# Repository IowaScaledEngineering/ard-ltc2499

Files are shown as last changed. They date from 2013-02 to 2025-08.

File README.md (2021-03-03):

# Iowa Scaled Engineering ARD-LTC2499

## Summary

The [ARD-LTC2499](https://www.iascaled.com/store/ARD-LTC2499) is an Arduino-compatible shield that contains a Linear Technology LTC2499 24-bit ADC
coupled with an LT6654 precision voltage reference. It is capable of converting 16 single-ended channels,
8 differential channels, or any other combination. In addition to measuring voltage, the ADC can interface
directly to a variety of sensors including strain gauges, thermocouples, and current shunts. The onboard EEPROM
can be used to store calibration and configuration information directly on each ARD-LTC2499 board.
A 6-byte EUI-48-compatible globally unique ID number is also provided.  The ARD-LTC2499 can be used with other
Arduino shields to make a simple, yet very accurate, data acquisition system.

Note:  The normal ARD-LTC2499 is not compatible with Arduinos using 3.3V I/O on the I2C lines, such as the Due, Zero, etc.
This is because the LTC2499 requires a 5V supply to deal with the 4.096V reference voltage, making it incompatible with 3.3V I2C.
A 3.3V compatible version is [available as the ARD-LTC2499-3V3](https://www.iascaled.com/store/ARD-LTC2499-3V3), which
is identical except that it also includes on-board level shifters for the I2C lines.

### Features

* Precision 24-bit delta sigma ADC in an Arduino-friendly form factor
* 16 single-ended channels, 8 differential channels, or any combination
* 7.5 samples/sec (or 15 samples/second without automatic offset cancellation)
* Input common mode voltage range of -0.3V to 5.3V
* Input measurement range of 0-2.048V (single-ended) or -2.048V to 2.048V (differential)
* 4.096V LT6654 precision voltage reference on board
* Optional onboard 5V linear regulator provides clean power to the ADC and reference
* 128 bytes of onboard EEPROM for storing configuration or calibration values
* Read-only 6-byte EUI-48-compatible globally unique ID
* Arduino software library for easy use
* 5V compatible I2C interface (or 3.3-5V with the ARD-LTC2499-3V3)

## Operation of the ARD-LTC2499 Hardware

The latest schematics for both the ARD-LTC2499 and the ARD-LTC2499-3V3 can be found here:
* [ARD-LTC2499 v1.3](https://github.com/IowaScaledEngineering/ard-ltc2499/raw/master/pg/ard-ltc2499-v1.3-83eb2df/ard-ltc2499.pdf)
* [ARD-LTC2499-3V3 v1.3](https://github.com/IowaScaledEngineering/ard-ltc2499/raw/master/pg/ard-ltc2499-v1.3LS-ffd4822/ard-ltc2499.pdf)

The Golden Rule:  When in doubt, check [the LTC2499
datasheet](https://www.analog.com/media/en/technical-documentation/data-sheets/2499fe.pdf).  This guide is not
designed to be a comprehensive guide to the LTC2499.

The useful measuring range of the inputs is 0V to 2.048V in single-ended mode, and a +/-2.048V in differential mode.
Be careful of common mode limits, however. Inputs have an absolute maximum common mode limit of -0.3V to +0.3V above VCC (nominally 5V)
before damage to the part will occur, so while the differential inputs can have -2.048V between them, neither side of the input may
violate the limit of -0.3V to 5.3V without damaging the part.

To eliminate any possibility of introducing gain or offset errors from buffering, the pins of the LTC2499 are brought directly
to the terminal headers. Please be careful when handling and using the board. Errant electrostatic discharge or voltages applied
outside the absolute maximum limits specified in the datasheet can cause immediate damage.

The 4.096V Reference output on J3 comes directly from the LT6654 reference output with no buffering. The LT6654 is rated for a
maximum of +/- 10mA. Also note that any current drawn from this pin will degrade the accuracy of the reference by a
small amount (see the Electrical Characteristics table, "Load Regulation", in the LT6654 datasheet).

### Hardware Configuration

In order to adapt to a wide variety of use cases and ArduinoTM configurations, the ARD-LTC2499 board has a number of configuration jumpers.

* JP1 - I2C Pull-up Enable
* JP2 - I2C Pin Selection
* JP3 - Onboard 5V Linear Regulator Enable
* JP4, JP5 & JP6 - LTC2499 I2C Address
* JP7 & JP8 - EEPROM I2C Address

_JP1 - I2C Pull-up Enable_

The I2C bus depends upon a set of pull-up resistors to function correctly. Each I2C bus should have one and only one set of
pull-ups enabled. The ARD-LTC2499 includes a set of 1.6k pull-up resistors that can be enabled by jumpering pins 1-2 and pins 3-4 of JP1.
Note that Arduino boards do not typically provide I2C pull-ups, so at least one board connected to I2C must provide them.

_JP2 - I2C Pin Selection_

Not all Arduinos provide I2C on the same pins. With the Rev 3 hardware designs (almost all of them as of 2021), there are now a
dedicated set of pins above AREF and GND marked "SDA" and "SCL". If you see those on your board, then place jumpers between
pins 3-5 and 4-6 on JP2 to connect the I2C bus to them.

If you board does not have explicit SDA and SCL pins, then most likely they're shared with pins A4 and A5. Place jumpers
between pins 1-3 and 2-4 to select those instead.

_JP3 - Onboard 5V Linear Regulator Enable_

To free the LTC2499 from any noise on the Arduino's 5V supply caused by the AVR or other shields, the ARD-LTC2499 includes an
onboard 78L05 regulator coming from the Arduino's "VIN" pin. If you are powering the Arduino with >8VDC via the power jack,
you can use the ARD-LTC2499 onboard 5V regulator to provide nice quiet power by jumpering pins 3-4 of JP3.

If you are powering the Arduino off of the 5V provided by USB or via some other means that does not place >8VDC on the VIN pin,
then the regulator will not work and must not be used. JP3 must be placed between pins 1-2 in this case.

_JP4, JP5 & JP6 - LTC2499 I2C Address_

Each device on the I2C bus must have a unique device address. The LTC2499 has 27 possible addresses depending on how
JP4, JP5, and JP6 are set. Each may be set high (jumpering pins 1-2, the two closest to the LTC2499), low (jumpering pins 3-4,
the ones furthest from the 2499) or floating (no jumpered pins or pins 2-3 jumpered).  JP4 corresponds to CA0, JP5 to CA1, and JP6 to CA2 on the LTC2499.

| JP4 | JP5 | JP6 | 7-bit I2C Address | Ard2499 Define |
|---|---|---|---|---|
| Low | Low | Low | 0x14 | ARD2499_ADC_ADDR_000 |
| Low | Low | Open | 0x15 | ARD2499_ADC_ADDR_00Z |
| Low | Low | High | 0x16 | ARD2499_ADC_ADDR_001 |
| Low | Open | Low | 0x17 | ARD2499_ADC_ADDR_0Z0 |
| Low | Open | Open | 0x24 | ARD2499_ADC_ADDR_0ZZ |
| Low | Open | High | 0x25 | ARD2499_ADC_ADDR_0Z1 |
| Low | High | Low | 0x26 | ARD2499_ADC_ADDR_010 |
| Low | High | Open | 0x27 | ARD2499_ADC_ADDR_01Z |
| Low | High | High | 0x28 | ARD2499_ADC_ADDR_011 |
| Open | Low | Low | 0x35 | ARD2499_ADC_ADDR_Z00 |
| Open | Low | Open | 0x36 | ARD2499_ADC_ADDR_Z0Z |
| Open | Low | High | 0x37 | ARD2499_ADC_ADDR_Z01 |
| Open | Open | Low | 0x44 | ARD2499_ADC_ADDR_ZZ0 |
| Open | Open | Open | 0x45 | ARD2499_ADC_ADDR_ZZZ |
| Open | Open | High | 0x46 | ARD2499_ADC_ADDR_ZZ1 |
| Open | High | Low | 0x47 | ARD2499_ADC_ADDR_Z10 |
| Open | High | Open | 0x54 | ARD2499_ADC_ADDR_Z1Z |
| Open | High | High | 0x55 | ARD2499_ADC_ADDR_Z11 |
| High | Low | Low | 0x56 | ARD2499_ADC_ADDR_100 |
| High | Low | Open | 0x57 | ARD2499_ADC_ADDR_10Z |
| High | Low | High | 0x64 | ARD2499_ADC_ADDR_101 |
| High | Open | Low | 0x65 | ARD2499_ADC_ADDR_1Z0 |
| High | Open | Open | 0x66 | ARD2499_ADC_ADDR_1ZZ |
| High | Open | High | 0x67 | ARD2499_ADC_ADDR_1Z1 |
| High | High | Low | 0x74 | ARD2499_ADC_ADDR_110 |
| High | High | Open | 0x75 | ARD2499_ADC_ADDR_11Z |
| High | High | High | 0x76 | ARD2499_ADC_ADDR_111 |

_JP7 & JP8 - EEPROM I2C Address_

Each device on the I2C bus must have a unique device address. The 24AA025E48 EEPROM that provides both non-volatile storage
and the globally unique ID number has four possible addresses depending on how JP7 and JP8 are set. Each may be set high (no jumper)
or low (jumper in place). Please refer to the Figure 5-2 in the 24AA025E48 datasheet (we use the SOT-23 version, so A2 is always '0' -
otherwise JP8 is A1 and JP7 is A0) or the Ard2499 library header for corresponding address values.

| JP7 | JP8 | 7-bit I2C Address | Ard2499 Define |
|---|---|---|---|
| Jumper | Jumper | 0x50 | ARD2499_EEP_ADDR_00 |
| Jumper | Open | 0x51 | ARD2499_EEP_ADDR_0Z |
| Open | Jumper | 0x52 | ARD2499_EEP_ADDR_Z0 |
| Open | Open | 0x53 | ARD2499_EEP_ADDR_ZZ |

## Ard2499 Arduino Software Library

### Introduction

The Ard2499 library was designed to make the Iowa Scaled Engineering ARD-LTC2499 shield easy to use with the Arduino environment.
The board itself is provides a breakout for the Linear Technology LTC2499 24-bit 8/16 channel delta-sigma ADC, adding other useful
features like a precision 4.096V LT6654 reference, 128 bytes of onboard EEPROM for storing configuration or calibration values,
and a read-only 6-byte EUI48-compatible globally unique ID number.

Note:  The software library is now maintained in [its own repository](https://github.com/IowaScaledEngineering/arduino-ard2499) for compatibility
with Arduino's Library Manager.

### Setup

There are two ways to install the Ard2499 library in the Arduino environment.

The easiest way is through Arduino's Library Manager.  You should be able to search for Ard2499 and have the library available for installation shortly.
We're working on it.

Alternately, you can [download the zip file](https://github.com/IowaScaledEngineering/arduino-ard2499/archive/main.zip) from the
IowaScaledEngineering/arduino-ard2499 project on Github and follow the ["Importing a .zip Library" instructions](https://www.arduino.cc/en/guide/libraries#toc4).

### Example Sketch

Once the library is installed, you should see Ard2499 under File->Examples in your Arduino environment.  A sample Arduino sketch that demonstrates some
simple uses of the library is available as ard2499_example directory.

### Library Usage Details

The core of the Ard2499 library is the Ard2499 object.  One instance should be instantiated for each ARD-LTC2499 board that you are using.

When an instance is created, an optional TwoWire object can be passed to the constructor.  Otherwise, the Ard2499 library assumes that the board will be communicating using the Wire object.

#### Functional Interface

```byte Ard2499::begin(byte ltc2499Address, byte eepromAddress, uint16_t referenceMillivolts = 4096);```

The Ard2499::begin() function should be called within the setup() function of your sketch. It requires the 7-bit address of both the LTC2499 and EEPROM on the ARD-LTC2499 to initialize both parts.
The addresses can be passed in directly as a number, or by using the address macros.  By using different addresses, it's possible to stack ARD-LTC2499 boards and have a different object to control each one.

An optional reference voltage, in millivolts, can be passed if the ARD-LTC2499 has a non-standard reference on board. If not specified, it defaults to 4096mV, which is the voltage
for any non-special order board.

Returns:  Ard2499::begin() will return a byte corresponding to a bitmast of errors, with 0 corresponding to complete success.
* ARD2499_SUCCESS (0x00) upon both devices being initialized successfully
* ARD2499_LTC2499_ERR (0x01) if the LTC2499 is not initialized successfully
* ARD2499_EEPROM_ERR (0x02) if the EEPROM is not initialized successfully

```byte Ard2499::ltc2499ChangeChannel(byte channel)```

The Ard2499::ltc2499ChangeChannel() function will wait for up to 200 milliseconds for the LTC2499 to become available, change the LTC2499's input multiplexer to the channel
specified in channel and start a new conversion. The value in channel corresponds to the lower 5 bits in the first configuration word of the device. In addition to computing
values for channel yourself, you can use the channel macros.

Additionally, channel can be configured to LTC2499_CHAN_TEMPERATURE to return the LTC2499 internal temperature. While the temperature input isn't a "channel" on the multiplexer,
the library makes it appear this way.

Returns:
* ARD2499_SUCCESS (0x00) if the channel change completed
* ARD2499_LTC2499_ERR (0x02) if the channel change failed

```byte Ard2499::ltc2499ChangeConfiguration(byte config)```

The Ard2499::ltc2499ChangeConfiguration() function will wait for up to 200 milliseconds for the LTC2499 to become available, change the LTC2499's configuration to that
specified in config and start a new conversion. The value in config corresponds to bits 3-5 in the second configuration word of the device. In addition to computing values
for config yourself, you can use the configuration macros.

Returns:
* ARD2499_SUCCESS (0x00) if the configuration change completed
* ARD2499_LTC2499_ERR (0x02) if the configuration change failed

```long Ard2499:: ltc2499Read()```

The Ard2499::ltc2499Read() function will wait for up to 200 milliseconds for the LTC2499 to become available, read the last conversion value, start a new conversion,
and clean up the conversion result.

Returns:
* -16777216 to +16777215 - normal conversion result
* LTC2499_READ_ERROR (0x01000001) if the read timed out or otherwise failed
* LTC2499_OVERRANGE_POSITIVE (0x01000000) if (IN+ - IN-) > 2.048V
* LTC2499_OVERRANGE_NEGATIVE (0x11000000) if (IN+ - IN-) < 2.048V

```long Ard2499:: ltc2499ReadAndChangeChannel(byte nextChannel)```

The Ard2499::ltc2499ReadAndChangeChannel() function will first attempt to change the input multiplexer channel and then perform a read. This is useful for not wasting
the conversion (and delay) resulting from a normal Ard2499::ltc2499Read() if the next operation is just going to be changing the input channel. Note: the channel change
does not take effect until after the data is read - in other words, for the next conversion.

Channel change behaviour works exactly like Ard2499::ltc2499ChangeChannel(). In the event that the channel change fails, LTC2499_READ_ERROR will be returned. Otherwise,
read and return behaviour works exactly like Ard2499::ltc2499Read().

```unsigned long Ard2499:: ltc2499ReadRaw()```

The Ard2499::ltc2499ReadRaw() function will wait for up to 200 milliseconds for the LTC2499 to become available, read the last conversion value, start a new conversion,
and return the native 32 bit conversion result. The lowest 6 bits will be "sub-LSB" bits, and the highest bit will be what the datasheet designates "SIG". This is for
advanced users who want direct access to the conversion result.

Returns:
* LTC2499_RAW_READ_ERROR (0xFFFFFFFF) if the read timed out or otherwise failed
* Any other result is a direct read from the LTC2499

```unsigned long Ard2499:: ltc2499ReadRawAndChangeChannel(byte nextChannel)```

The Ard2499::ltc2499ReadRawAndChangeChannel() function will first attempt to change the input multiplexer channel and then perform a raw read. This is useful for
not wasting the conversion (and delay) resulting from a normal Ard2499::ltc2499ReadRaw() if the next operation is just going to be changing the input channel.
Note: the channel change does not take effect until after the data is read - in other words, for the next conversion. The raw read capability is for advanced
users who want direct access to the conversion result.

Channel change behaviour works exactly like Ard2499::ltc2499ChangeChannel(). In the event that the channel change fails, LTC2499_RAW_READ_ERROR will be returned.
Otherwise, read and return behaviour works exactly like Ard2499:: ltc2499ReadRaw().

```unsigned int Ard2499:: ltc2499ReadTemperatureDeciK()```

The Ard2499::ltc2499ReadTemperatureDeciK() function will check if the current channel is LTC2499_CHAN_TEMPERATURE and if not, wait up to 200 milliseconds for
converter availability, change it and start a new conversion. It will then wait for up to 200 milliseconds for the LTC2499 to complete the conversion and turn it
into a unsigned int corresponding to the LTC2499's current temperature in 1/10th degrees Kelvin.

Upon failure, it will return zero, as hopefully no project you're working on is operating at absolute zero. If it is and the part still seems to be working
otherwise, call us and we'll help you write the paper for your physics journal of choice.

```float ltc2499ReadTemperature(byte temperatureUnits)```

The Ard2499::ltc2499ReadTemperature() function will check if the current channel is LTC2499_CHAN_TEMPERATURE and if not, wait up to 200 milliseconds for converter
availability, change it and start a new conversion. It will then wait for up to 200 milliseconds for the LTC2499 to complete the conversion and turn it into single
precision floating point value corresponding to the LTC2499's current temperature in the units specified in temperatureUnits.

Upon failure, it will return zero.

The value of temperatureUnits should be ARD2499_TEMP_K (degrees Kelvin), ARD2499_TEMP_C (degrees Celsius), or ARD2499_TEMP_F (degrees Fahrenheit).

Note: Because this function uses floating point on an 8 bit processor without any sort of hardware floating point support, expect performance to be abysmal on
AVR-based Arduinos. But it's handy if you don't care about performance.

```const char* Ard2499::eui48Get()```

The Ard2499::eui48Get() function will retrieve the board's 48-bit, globally unique, EUI-48TM-compatible identification number as a string.

Returns:

Ard2499::eui48Get() will return a character pointer to a constant, NULL-terminated string. The value will be either 12 characters of hexadecimal number,
or "Unknown" if the Ard2499::begin() failed to find the EEPROM. (Ard2499::begin() would have returned a value with the ARD2499_EEPROM_ERR bit set.)

```byte Ard2499::eepromRead(int address, byte defaultOnError=0x00)```

The Ard2499::eepromRead() function will retrieve a byte from the ARD-LTC2499's onboard EEPROM at the location specified by address. Valid values for address are 0x00-0x7F.

Optionally, the function can take a second argument - defaultOnError - of the value to be returned if the EEPROM is not initialized or is not accessible when the function
is called. If the defaultOnError parameter is omitted, it will default to returning 0x00 on failure.

```byte Ard2499::eepromWrite(int address, byte value, byte blocking=1)```

The Ard2499::eepromWrite() function will write a byte of value value to the ARD-LTC2499's onboard EEPROM at the location specified by address. Valid values for address are
0x00-0x7F, and value can be 0x00-0xFF.

Optionally, the function can take a third argument - blocking. The Microchip 24AA025E48 EEPROM used on the ARD-LTC2499 can take up to 5 milliseconds to actually commit
a write to EEPROM. If blocking is non-zero or omitted, the eepromWrite() function will block until it can confirm that the write is completed or until it times out
after 10 millseconds.

Note that blocking will not cause the value to be verified - it merely causes the function to block until the part begins acknowledging I2C/TWI transactions once
again, indicating that the write cycle is complete.

Returns:
* ARD2499_SUCCESS (0x00) if the write completed
* ARD2499_EEPROM_ERR (0x02) if the write failed

#### LTC2499 Address Defines

The address for the LTC2499 is configurable on the ARD-LTC2499 using jumpers JP4-JP6. You can either use the datasheet and directly enter the LTC2499's address into
the Ard2499::begin() function, or use some convenient macros.

The macros are all in the form of ARD2499_ADC_ADDR_cba, where a, b, and c can take on the value of '0', '1', or 'Z'. Placeholder 'a' represents jumper JP4, 'b' represents JP5,
and 'c' JP6. '0' indicates that the center pin is jumpered to the low pins (towards inputs 8-15 on the board), '1' indicates that it is jumpered to the high pins
(towards the LTC2499 or inputs 0-7), and 'Z' indicates that it's left floating (no jumpers or jumper across pin 2-3).

So, if all three were left open, you'd use ARD2499_ADC_ADDR_ZZZ. Likewise, for JP4 to bottom, JP5 to top, and JP6 open you'd use ARD2499_ADC_ADDR_Z10.

#### EEPROM Address Defines

The address for the EEPROM is configurable on the ARD-LTC2499 using jumpers JP7-JP8. You can either use the datasheet and directly enter the 24AA025E48's address into the
Ard2499::begin() function, or use some convenient macros.

The macros are all in the form of ARD2499_EEP_ADDR_ba, where a and b can take on the value of '0' or 'Z'. Placeholder 'a' represents jumper JP7 and 'b' represents JP8.
'0' indicates that a jumper has been placed across those pins, and 'Z' indicates that it's left floating (no jumper).

So, if both were left open, you'd use ARD2499_EEP_ADDR_ZZ. Likewise, for JP7 jumpered and JP8 open ARD2499_EEP_ADDR_Z0.

#### Channel Defines

The library provides definitions of all the common channel combinations to allow the easy selection of input channels without knowing all the internal LTC2499 bits to set.

Differential configurations take the form LTC2499_CHAN_DIFF_aP_bN, where 'a' represents the channel number of the positive input (IN+ in the LTC2499 datasheet)
and 'b' represents the channel number of the negative input (IN-).

Single-ended configurations are in the form LTC2499_CHAN_SINGLE_aP, where again 'a' represents the channel number of the positive (IN+) input.

Additionally, the internal temperature sensor can be selected by using LTC2499_CHAN_TEMPERATURE.

Some examples:
* LTC2499_CHAN_DIFF_2P_3N - Differential, input 2 is IN+, input 3 is IN-
* LTC2499_CHAN_DIFF_11P_10N - Differential, input 11 is IN+, input 10 is IN-
* LTC2499_CHAN_SINGLE_2P - Single ended, input 2 as IN+
* LTC2499_CHAN_SINGLE_10P - Single ended, input 10 as IN+
* LTC2499_CHAN_TEMPERATURE - Connect to internal temperature sensor.

#### Configuration Macros

Bit position macros are provided corresponding to the bits used to define the LTC2499 configuration in the second configuration byte:
* LTC2499_CONFIG2_FA
* LTC2499_CONFIG2_FB
* LTC2499_CONFIG2_SPD

These can be combined into a configuration value by an expression such as:

(_BV(LTC2499_CONFIG2_FA) | _BV(LTC2499_CONFIG2_SPD))

Please see the LTC2499 datasheet, Table 4, to see how these are used directly.

Additionally, the library has some convenient combinations:
* LTC2499_CONFIG2_50HZ_REJ - Reject at 50Hz
* LTC2499_CONFIG2_60HZ_REJ - Reject at 60Hz
* LTC2499_CONFIG2_60_50HZ_REJ - Reject at both 50/60Hz
* LTC2499_CONFIG2_SPEED_2X - Set for double speed conversions, drop offset calibration (15 samples/sec)

To use these, pick one of the rejection configurations and - optionally - bitwise or it with the double speed option and pass it to the the ltc2499ChangeConfiguration() function. For example:

```retval = ard2499.ltc2499ChangeConfiguration(LTC2499_CONFIG2_60_50HZ_REJ | LTC2499_CONFIG2_SPEED_2X)```

### A Note About Converter Latency

Important! Note that the LTC2499 will start a conversion whenever it is read (using ltc2499Read() or similar) or whenever the channel
or configuration is changed. Each conversion will take ~133 milliseconds in 1X mode and ~67 milliseconds in 2X mode. During this conversion time,
the LTC2499 will not respond to I2C/TWI requests. Thus, all calls interacting with the LTC2499 implement code to block until a sane timeout is
reached or the part starts responding. Be aware that when you use these functions, your code may hang up for a conversion time.

To minimize the wasted conversions, functions that read the current value and immediately change the channel (without wasting an entire
conversion cycle in between) are provided in addition to the standard read and channel change functions.

### Source Releases

The latest source code is always available from our GitHub [arduino-ard2499 repository](https://github.com/IowaScaledEngineering/arduino-ard2499).  We've broken it out
from the [main hardware project](https://github.com/IowaScaledEngineering/ard-ltc2499) to allow it to be included into Arduino's Library Manager automatically.

## Open Hardware & Software

Like all public Iowa Scaled Engineering designs, the ARD-LTC2499 is both open hardware and open source software.  The hardware is licensed under Creative Commons BY-SA, and the software is GPL v3.

The board was designed using the gEDA suite of tools (gschem, pcb, etc.), and the files are in the sch, sym, and pcb subdirectories.

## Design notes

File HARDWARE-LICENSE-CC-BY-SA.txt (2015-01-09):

The hardware design files for the Iowa Scaled Engineering ARD-LTC2499 are
open hardware, and licensed under the Creative Commons Attribution-Share
Alike license.

A copy can be found below, or from 
  http://creativecommons.org/licenses/by-sa/4.0/legalcode
-----------------------------------------------------------------------------

Creative Commons Attribution-ShareAlike 4.0 International Public License

By exercising the Licensed Rights (defined below), You accept and agree to
be bound by the terms and conditions of this Creative Commons
Attribution-ShareAlike 4.0 International Public License ("Public License").
To the extent this Public License may be interpreted as a contract, You are
granted the Licensed Rights in consideration of Your acceptance of these
terms and conditions, and the Licensor grants You such rights in
consideration of benefits the Licensor receives from making the Licensed
Material available under these terms and conditions.

Section 1 – Definitions.

    Adapted Material means material subject to Copyright and Similar Rights
that is derived from or based upon the Licensed Material and in which the
Licensed Material is translated, altered, arranged, transformed, or
otherwise modified in a manner requiring permission under the Copyright and
Similar Rights held by the Licensor. For purposes of this Public License,
where the Licensed Material is a musical work, performance, or sound
recording, Adapted Material is always produced where the Licensed Material
is synched in timed relation with a moving image.
    Adapter's License means the license You apply to Your Copyright and
Similar Rights in Your contributions to Adapted Material in accordance with
the terms and conditions of this Public License.
    BY-SA Compatible License means a license listed at
creativecommons.org/compatiblelicenses, approved by Creative Commons as
essentially the equivalent of this Public License.
    Copyright and Similar Rights means copyright and/or similar rights
closely related to copyright including, without limitation, performance,
broadcast, sound recording, and Sui Generis Database Rights, without regard
to how the rights are labeled or categorized. For purposes of this Public
License, the rights specified in Section 2(b)(1)-(2) are not Copyright and
Similar Rights.
    Effective Technological Measures means those measures that, in the
absence of proper authority, may not be circumvented under laws fulfilling
obligations under Article 11 of the WIPO Copyright Treaty adopted on
December 20, 1996, and/or similar international agreements.
    Exceptions and Limitations means fair use, fair dealing, and/or any
other exception or limitation to Copyright and Similar Rights that applies
to Your use of the Licensed Material.
    License Elements means the license attributes listed in the name of a
Creative Commons Public License. The License Elements of this Public License
are Attribution and ShareAlike.
    Licensed Material means the artistic or literary work, database, or
other material to which the Licensor applied this Public License.
    Licensed Rights means the rights granted to You subject to the terms and
conditions of this Public License, which are limited to all Copyright and
Similar Rights that apply to Your use of the Licensed Material and that the
Licensor has authority to license.
    Licensor means the individual(s) or entity(ies) granting rights under
this Public License.
    Share means to provide material to the public by any means or process
that requires permission under the Licensed Rights, such as reproduction,
public display, public performance, distribution, dissemination,
communication, or importation, and to make material available to the public
including in ways that members of the public may access the material from a
place and at a time individually chosen by them.
    Sui Generis Database Rights means rights other than copyright resulting
from Directive 96/9/EC of the European Parliament and of the Council of 11
March 1996 on the legal protection of databases, as amended and/or
succeeded, as well as other essentially equivalent rights anywhere in the
world.
    You means the individual or entity exercising the Licensed Rights under
this Public License. Your has a corresponding meaning.

Section 2 – Scope.

    License grant.
        Subject to the terms and conditions of this Public License, the
Licensor hereby grants You a worldwide, royalty-free, non-sublicensable,
non-exclusive, irrevocable license to exercise the Licensed Rights in the
Licensed Material to:
            reproduce and Share the Licensed Material, in whole or in part;
and
            produce, reproduce, and Share Adapted Material.
        Exceptions and Limitations. For the avoidance of doubt, where
Exceptions and Limitations apply to Your use, this Public License does not
apply, and You do not need to comply with its terms and conditions.
        Term. The term of this Public License is specified in Section 6(a).
        Media and formats; technical modifications allowed. The Licensor
authorizes You to exercise the Licensed Rights in all media and formats
whether now known or hereafter created, and to make technical modifications
necessary to do so. The Licensor waives and/or agrees not to assert any
right or authority to forbid You from making technical modifications
necessary to exercise the Licensed Rights, including technical modifications
necessary to circumvent Effective Technological Measures. For purposes of
this Public License, simply making modifications authorized by this Section
2(a)(4) never produces Adapted Material.
        Downstream recipients.
            Offer from the Licensor – Licensed Material. Every recipient of
the Licensed Material automatically receives an offer from the Licensor to
exercise the Licensed Rights under the terms and conditions of this Public
License.
            Additional offer from the Licensor – Adapted Material. Every
recipient of Adapted Material from You automatically receives an offer from
the Licensor to exercise the Licensed Rights in the Adapted Material under
the conditions of the Adapter’s License You apply.
            No downstream restrictions. You may not offer or impose any
additional or different terms or conditions on, or apply any Effective
Technological Measures to, the Licensed Material if doing so restricts
exercise of the Licensed Rights by any recipient of the Licensed Material.
        No endorsement. Nothing in this Public License constitutes or may be
construed as permission to assert or imply that You are, or that Your use of
the Licensed Material is, connected with, or sponsored, endorsed, or granted
official status by, the Licensor or others designated to receive attribution
as provided in Section 3(a)(1)(A)(i).

    Other rights.
        Moral rights, such as the right of integrity, are not licensed under
this Public License, nor are publicity, privacy, and/or other similar
personality rights; however, to the extent possible, the Licensor waives
and/or agrees not to assert any such rights held by the Licensor to the
limited extent necessary to allow You to exercise the Licensed Rights, but
not otherwise.
        Patent and trademark rights are not licensed under this Public
License.
        To the extent possible, the Licensor waives any right to collect
royalties from You for the exercise of the Licensed Rights, whether directly
or through a collecting society under any voluntary or waivable statutory or
compulsory licensing scheme. In all other cases the Licensor expressly
reserves any right to collect such royalties.

Section 3 – License Conditions.

Your exercise of the Licensed Rights is expressly made subject to the
following conditions.

    Attribution.

        If You Share the Licensed Material (including in modified form), You
must:
            retain the following if it is supplied by the Licensor with the
Licensed Material:
                identification of the creator(s) of the Licensed Material
and any others designated to receive attribution, in any reasonable manner
requested by the Licensor (including by pseudonym if designated);
                a copyright notice;
                a notice that refers to this Public License;
                a notice that refers to the disclaimer of warranties;
                a URI or hyperlink to the Licensed Material to the extent
                reasonably practicable;
            indicate if You modified the Licensed Material and retain an
indication of any previous modifications; and
            indicate the Licensed Material is licensed under this Public
License, and include the text of, or the URI or hyperlink to, this Public
License.
        You may satisfy the conditions in Section 3(a)(1) in any reasonable
manner based on the medium, means, and context in which You Share the
Licensed Material. For example, it may be reasonable to satisfy the
conditions by providing a URI or hyperlink to a resource that includes the
required information.
        If requested by the Licensor, You must remove any of the information
required by Section 3(a)(1)(A) to the extent reasonably practicable.
    ShareAlike.

    In addition to the conditions in Section 3(a), if You Share Adapted
Material You produce, the following conditions also apply.
        The Adapter’s License You apply must be a Creative Commons license
with the same License Elements, this version or later, or a BY-SA Compatible
License.
        You must include the text of, or the URI or hyperlink to, the
Adapter's License You apply. You may satisfy this condition in any
reasonable manner based on the medium, means, and context in which You Share
Adapted Material.
        You may not offer or impose any additional or different terms or
conditions on, or apply any Effective Technological Measures to, Adapted
Material that restrict exercise of the rights granted under the Adapter's
License You apply.

Section 4 – Sui Generis Database Rights.

Where the Licensed Rights include Sui Generis Database Rights that apply to
Your use of the Licensed Material:

    for the avoidance of doubt, Section 2(a)(1) grants You the right to
extract, reuse, reproduce, and Share all or a substantial portion of the
contents of the database;
    if You include all or a substantial portion of the database contents in
a database in which You have Sui Generis Database Rights, then the database
in which You have Sui Generis Database Rights (but not its individual
contents) is Adapted Material, including for purposes of Section 3(b); and
    You must comply with the conditions in Section 3(a) if You Share all or
a substantial portion of the contents of the database.

For the avoidance of doubt, this Section 4 supplements and does not replace
Your obligations under this Public License where the Licensed Rights include
other Copyright and Similar Rights.

Section 5 – Disclaimer of Warranties and Limitation of Liability.

    Unless otherwise separately undertaken by the Licensor, to the extent
possible, the Licensor offers the Licensed Material as-is and as-available,
and makes no representations or warranties of any kind concerning the
Licensed Material, whether express, implied, statutory, or other. This
includes, without limitation, warranties of title, merchantability, fitness
for a particular purpose, non-infringement, absence of latent or other
defects, accuracy, or the presence or absence of errors, whether or not
known or discoverable. Where disclaimers of warranties are not allowed in
full or in part, this disclaimer may not apply to You.
    To the extent possible, in no event will the Licensor be liable to You
on any legal theory (including, without limitation, negligence) or otherwise
for any direct, special, indirect, incidental, consequential, punitive,
exemplary, or other losses, costs, expenses, or damages arising out of this
Public License or use of the Licensed Material, even if the Licensor has
been advised of the possibility of such losses, costs, expenses, or damages.
Where a limitation of liability is not allowed in full or in part, this
limitation may not apply to You.

    The disclaimer of warranties and limitation of liability provided above
shall be interpreted in a manner that, to the extent possible, most closely
approximates an absolute disclaimer and waiver of all liability.

Section 6 – Term and Termination.

    This Public License applies for the term of the Copyright and Similar
Rights licensed here. However, if You fail to comply with this Public
License, then Your rights under this Public License terminate automatically.

    Where Your right to use the Licensed Material has terminated under
Section 6(a), it reinstates:
        automatically as of the date the violation is cured, provided it is
cured within 30 days of Your discovery of the violation; or
        upon express reinstatement by the Licensor.
    For the avoidance of doubt, this Section 6(b) does not affect any right
the Licensor may have to seek remedies for Your violations of this Public
License.
    For the avoidance of doubt, the Licensor may also offer the Licensed
Material under separate terms or conditions or stop distributing the
Licensed Material at any time; however, doing so will not terminate this
Public License.
    Sections 1, 5, 6, 7, and 8 survive termination of this Public License.

Section 7 – Other Terms and Conditions.

    The Licensor shall not be bound by any additional or different terms or
conditions communicated by You unless expressly agreed.
    Any arrangements, understandings, or agreements regarding the Licensed
Material not stated herein are separate from and independent of the terms
and conditions of this Public License.

Section 8 – Interpretation.

    For the avoidance of doubt, this Public License does not, and shall not
be interpreted to, reduce, limit, restrict, or impose conditions on any use
of the Licensed Material that could lawfully be made without permission
under this Public License.
    To the extent possible, if any provision of this Public License is
deemed unenforceable, it shall be automatically reformed to the minimum
extent necessary to make it enforceable. If the provision cannot be
reformed, it shall be severed from this Public License without affecting the
enforceability of the remaining terms and conditions.
    No term or condition of this Public License will be waived and no
failure to comply consented to unless expressly agreed to by the Licensor.
    Nothing in this Public License constitutes or may be interpreted as a
limitation upon, or waiver of, any privileges and immunities that apply to
the Licensor or You, including from the legal processes of any jurisdiction
or authority.

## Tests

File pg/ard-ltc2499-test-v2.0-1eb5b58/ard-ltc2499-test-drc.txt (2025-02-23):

** Drc report for /tank/data/design/projects/ard-ltc2499/kicad/ard-ltc2499-test/ard-ltc2499-test.kicad_pcb **
** Created on 2025-02-22 22:39:23 **

** Found 0 DRC violations **

** Found 0 unconnected pads **

** Found 0 Footprint errors **

** End of Report **

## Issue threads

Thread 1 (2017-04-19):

Add shorted solder jumper to connect COM to GND.

petersenm, 2017-04-19:
Allows option to float COM to some other voltage for lifted single-ended measurements.

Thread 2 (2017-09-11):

Inputs 8-15 collide with programming/SPI header on Arduino board

petersenm, 2017-09-11:

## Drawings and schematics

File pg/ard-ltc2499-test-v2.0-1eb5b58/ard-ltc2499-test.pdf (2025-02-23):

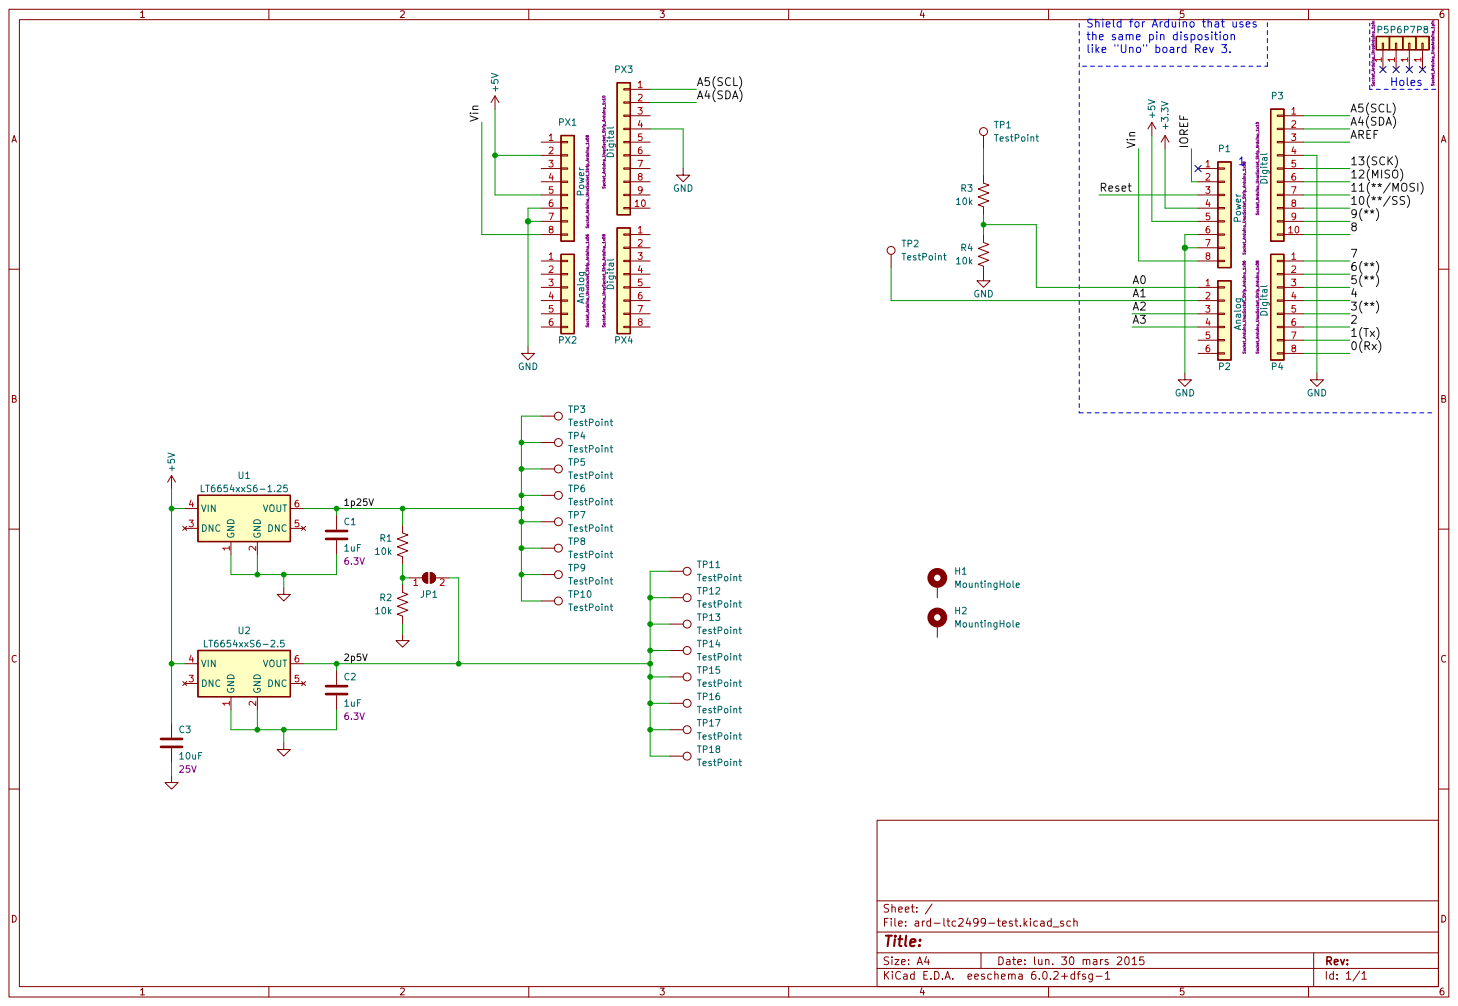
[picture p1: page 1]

the same pin disposition
like "Uno" board Rev 3.
1023456789 P3 Digital Socket_Arduino_Uno:Socket_Strip_Arduino_1x10 123456 P2 Analog Socket_Arduino_Uno:Socket_Strip_Arduino_1x06

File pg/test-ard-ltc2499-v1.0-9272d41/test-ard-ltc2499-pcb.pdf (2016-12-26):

# test-ard-ltc2499.pcb

# 1. Table of Contents (This Page) Created on Sun Dec 25 20:49:59 2016

# 2. component 3. solder 4. outline 5. plated-drill 6. unplated-drill 7. componentmask 8. soldermask 9. topsilk 10. bottomsilk 11. toppaste 12. topassembly 13. bottomassembly 14. fab

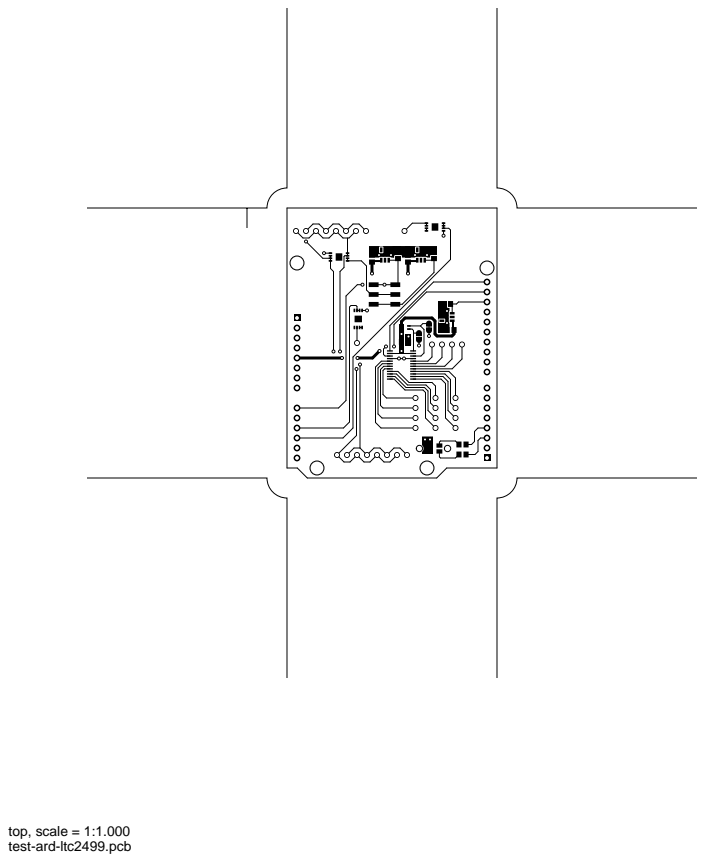
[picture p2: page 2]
top, scale = 1:1.000

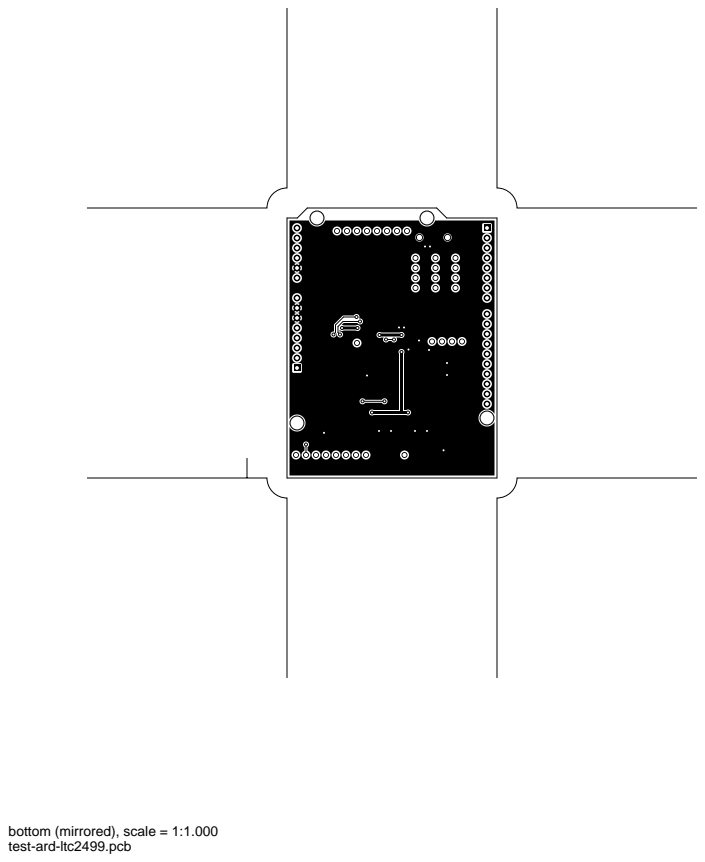
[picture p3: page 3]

bottom (mirrored), scale = 1:1.000

outline, scale = 1:1.000

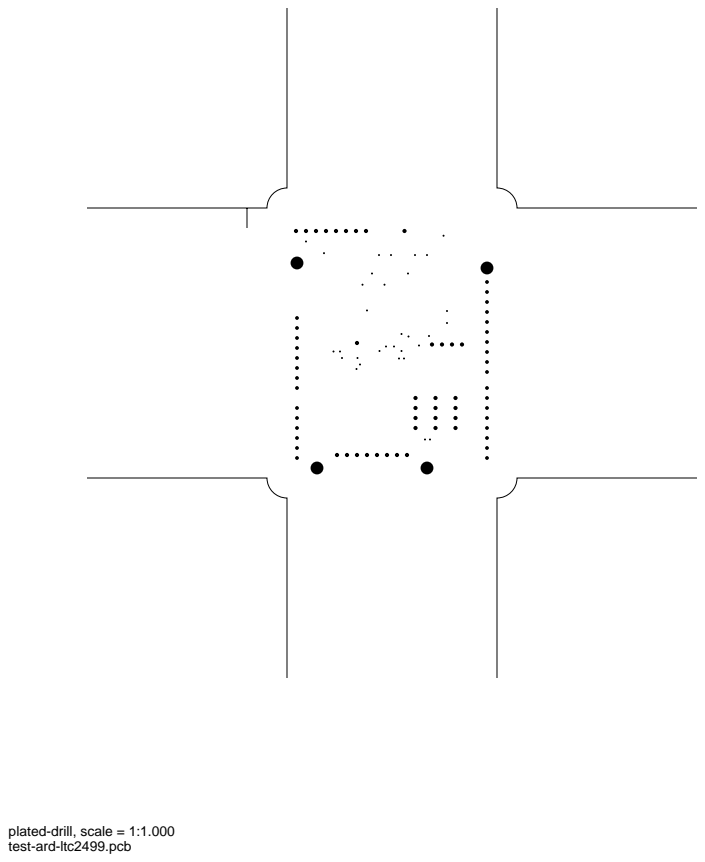
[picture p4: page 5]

plated-drill, scale = 1:1.000

unplated-drill, scale = 1:1.000

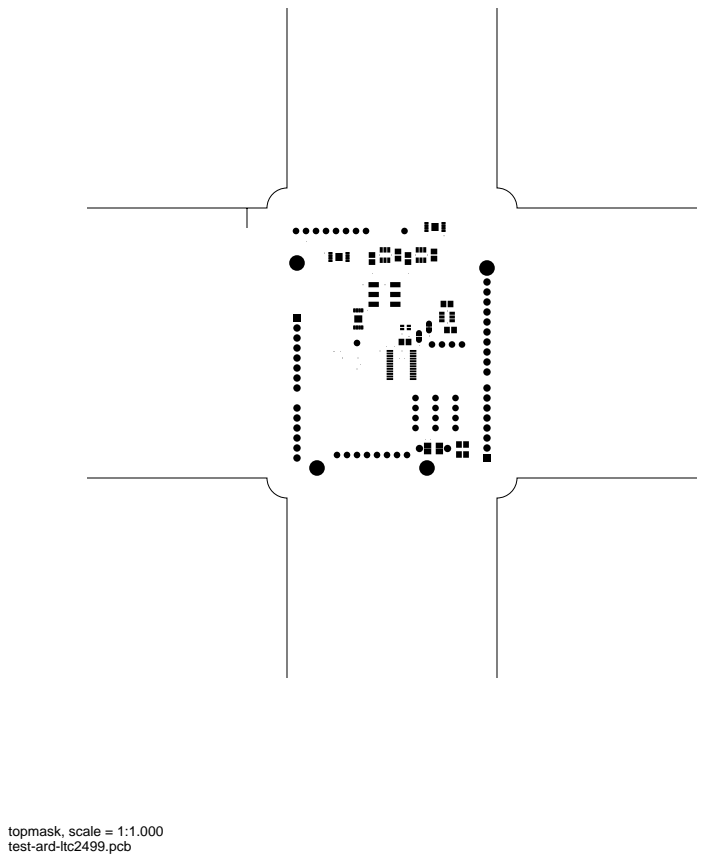
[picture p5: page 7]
topmask, scale = 1:1.000

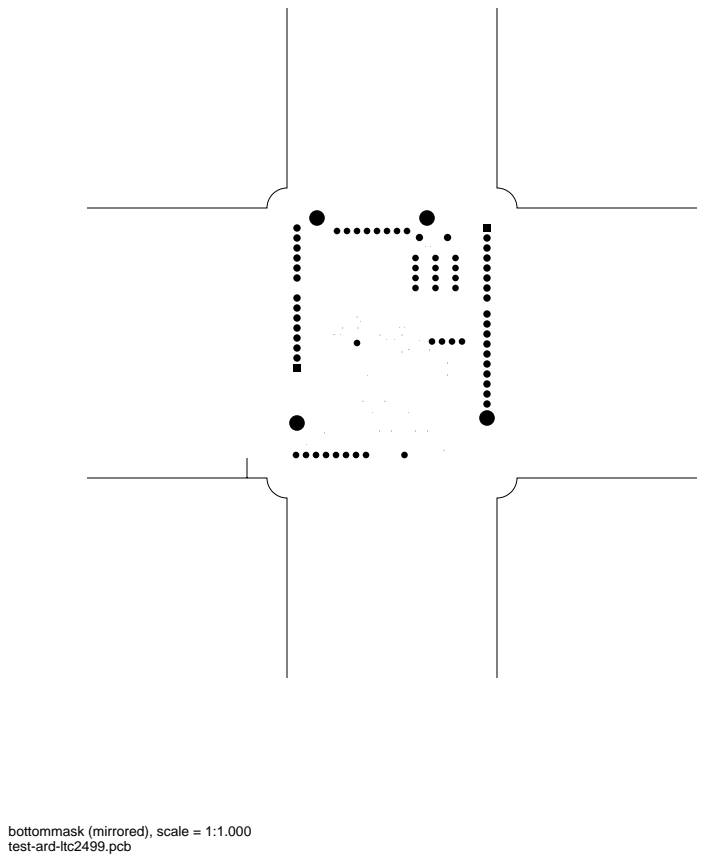
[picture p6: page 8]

bottommask (mirrored), scale = 1:1.000

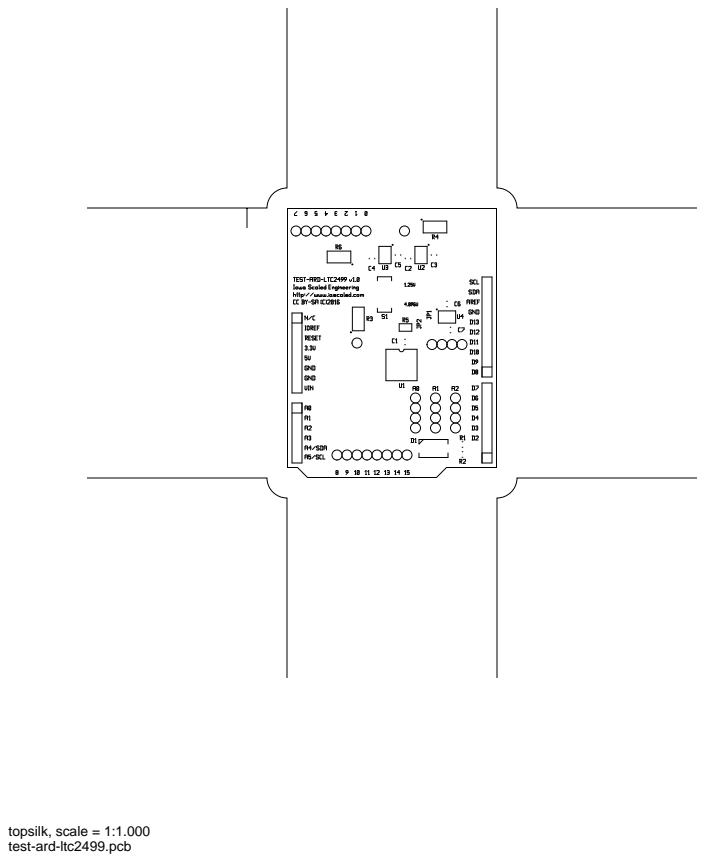
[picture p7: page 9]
topsilk, scale = 1:1.000

bottomsilk (mirrored), scale = 1:1.000

toppaste, scale = 1:1.000

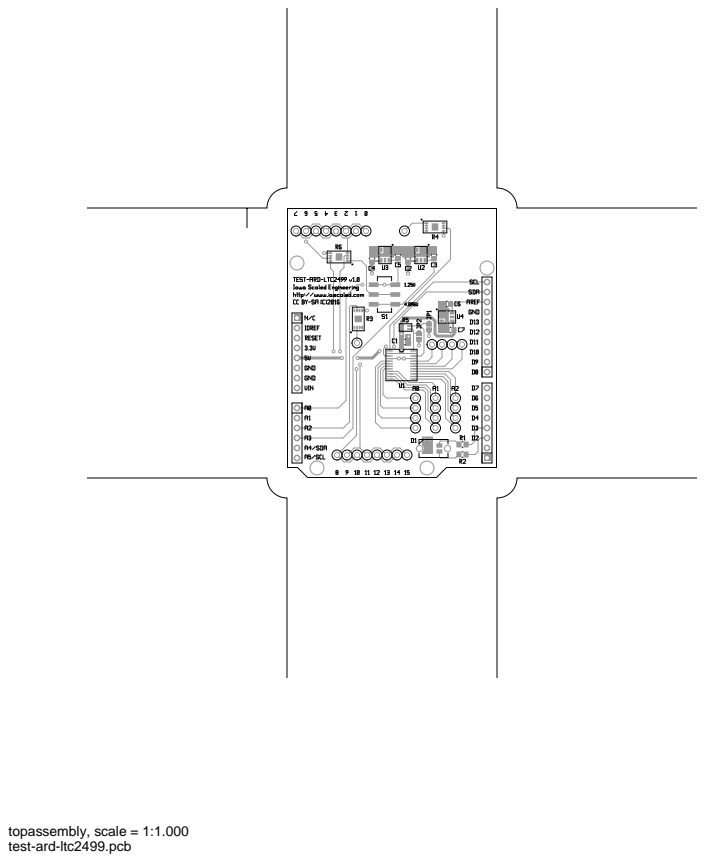
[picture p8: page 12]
topassembly, scale = 1:1.000

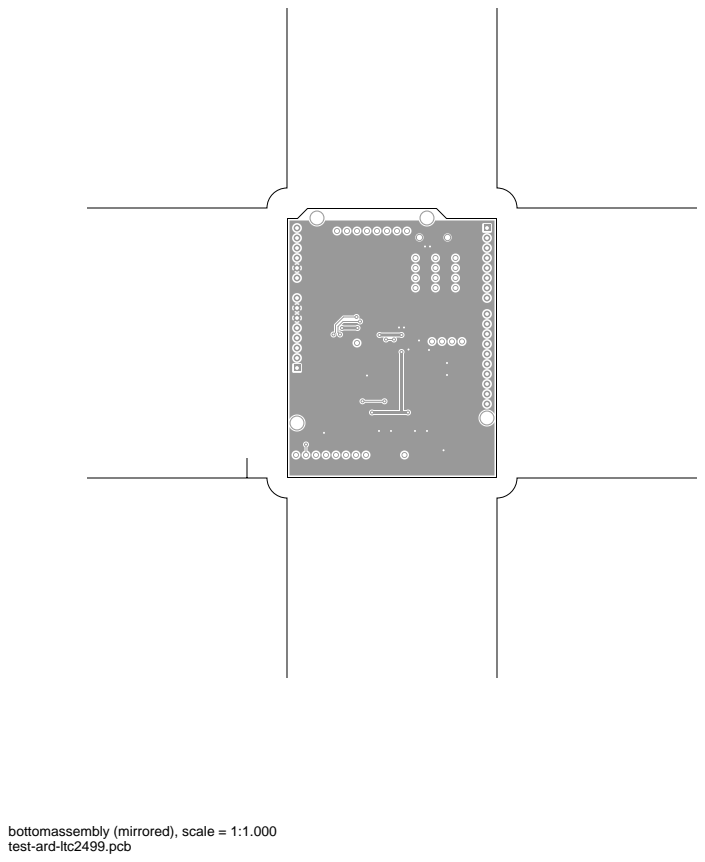
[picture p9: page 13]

bottomassembly (mirrored), scale = 1:1.000

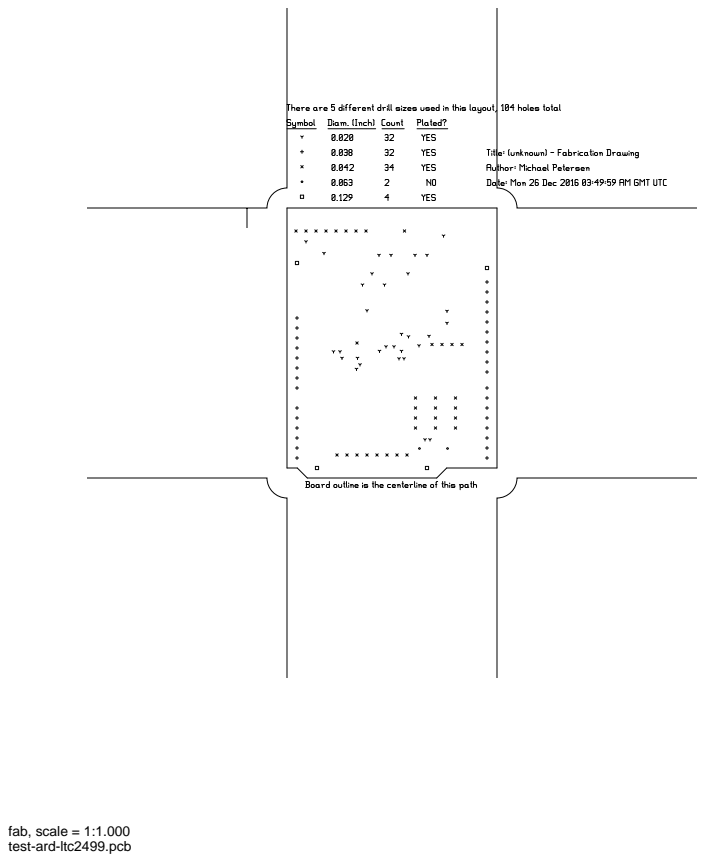
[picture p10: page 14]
fab, scale = 1:1.000

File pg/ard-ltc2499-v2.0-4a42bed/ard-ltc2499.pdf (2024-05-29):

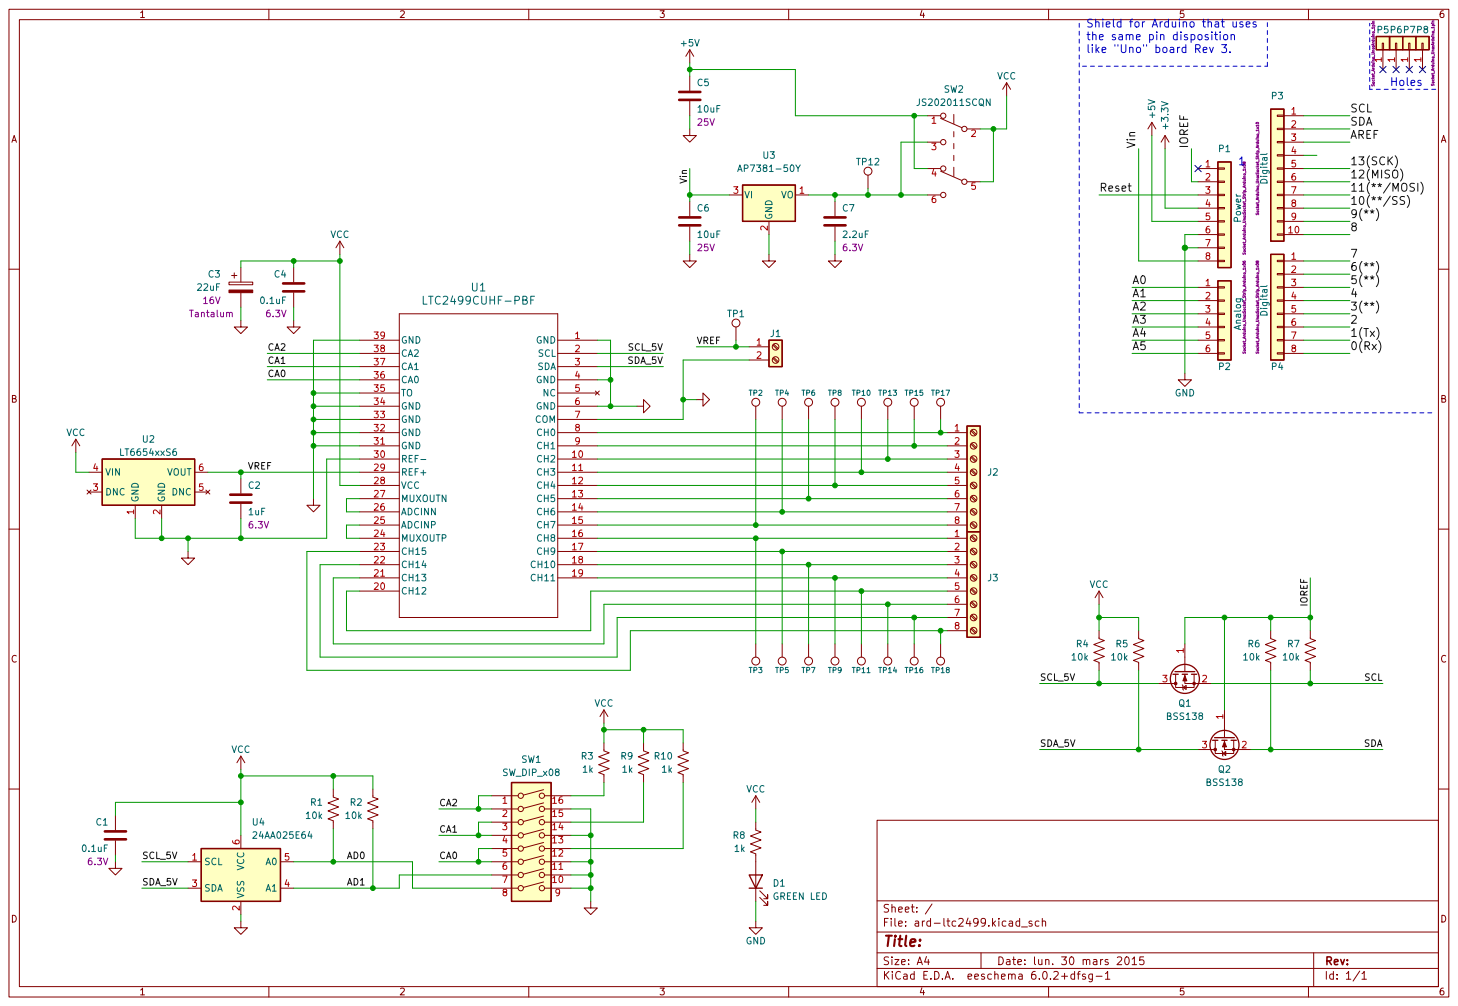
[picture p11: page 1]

Shield for Arduino that uses
the same pin disposition

2 DNC 3 VIN 4 DNC 5 VOUT 6 U2

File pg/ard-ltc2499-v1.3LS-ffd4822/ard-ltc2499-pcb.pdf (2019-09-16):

# ard-ltc2499.pcb

# 1. Table of Contents (This Page) Created on Thu Dec 22 11:12:02 2016

# 2. component 3. solder 4. outline 5. plated-drill 6. componentmask 7. soldermask 8. topsilk 9. bottomsilk 10. toppaste 11. bottompaste 12. topassembly 13. bottomassembly 14. fab

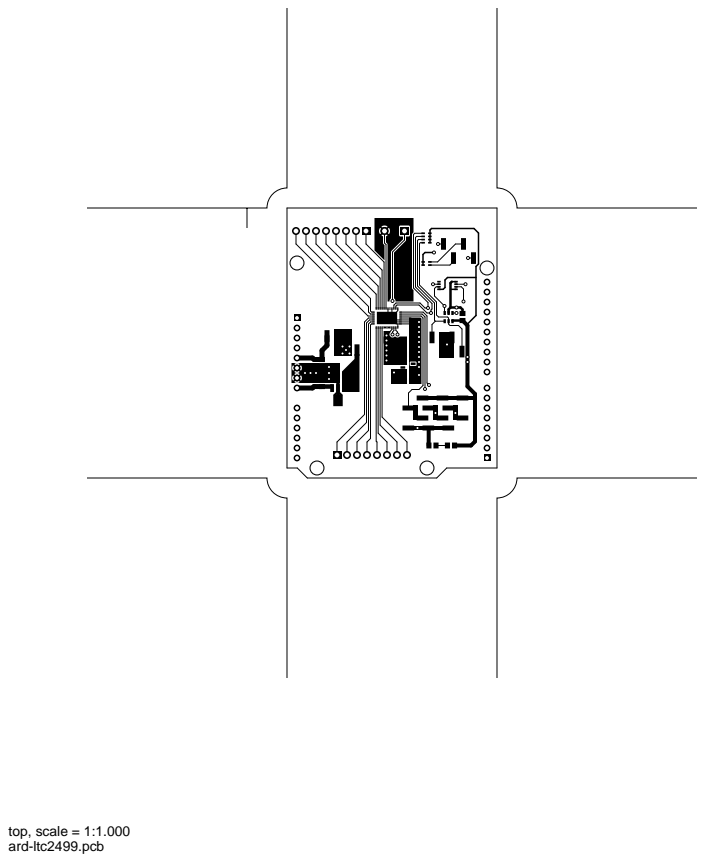
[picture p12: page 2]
top, scale = 1:1.000


bottom (mirrored), scale = 1:1.000

outline, scale = 1:1.000


plated-drill, scale = 1:1.000

topmask, scale = 1:1.000


bottommask (mirrored), scale = 1:1.000

topsilk, scale = 1:1.000


bottomsilk (mirrored), scale = 1:1.000

toppaste, scale = 1:1.000 bottompaste (mirrored), scale = 1:1.000

topassembly, scale = 1:1.000


bottomassembly (mirrored), scale = 1:1.000

fab, scale = 1:1.000

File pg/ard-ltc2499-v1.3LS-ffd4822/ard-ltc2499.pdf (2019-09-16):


SDA

5 READY

Place C2 and C3 near LTC2499 VCC pin.

Local regulator to provide quiet 5V.
Can only be used when VIN is present.

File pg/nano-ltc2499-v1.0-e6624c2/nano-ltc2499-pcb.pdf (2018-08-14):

# nano-ltc2499.pcb

# 1. Table of Contents (This Page) Created on Wed Aug 1 09:37:01 2018

# 2. component 3. solder 4. outline 5. plated-drill 6. componentmask 7. soldermask 8. topsilk 9. bottomsilk 10. toppaste 11. topassembly 12. bottomassembly 13. fab

top, scale = 1:1.000


bottom (mirrored), scale = 1:1.000

outline, scale = 1:1.000


plated-drill, scale = 1:1.000

topmask, scale = 1:1.000


bottommask (mirrored), scale = 1:1.000


topsilk, scale = 1:1.000


bottomsilk (mirrored), scale = 1:1.000

toppaste, scale = 1:1.000

topassembly, scale = 1:1.000


bottomassembly (mirrored), scale = 1:1.000

fab, scale = 1:1.000

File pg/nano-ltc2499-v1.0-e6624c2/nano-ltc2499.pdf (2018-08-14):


Place C5 and C6 near LTC2499 VCC pin.

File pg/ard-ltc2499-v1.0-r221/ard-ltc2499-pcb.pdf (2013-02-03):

# ard-ltc2499.pcb

# 1. Table of Contents (This Page) Created on Sat Feb 2 13:58:03 2013

# 2. component 3. solder 4. outline 5. plated-drill 6. componentmask 7. soldermask 8. topsilk 9. bottomsilk 10. toppaste 11. topassembly 12. bottomassembly 13. fab

top, scale = 1:1.000


bottom (mirrored), scale = 1:1.000

outline, scale = 1:1.000


plated-drill, scale = 1:1.000

topmask, scale = 1:1.000


bottommask (mirrored), scale = 1:1.000

topsilk, scale = 1:1.000

bottomsilk (mirrored), scale = 1:1.000

toppaste, scale = 1:1.000

topassembly, scale = 1:1.000


bottomassembly (mirrored), scale = 1:1.000

fab, scale = 1:1.000

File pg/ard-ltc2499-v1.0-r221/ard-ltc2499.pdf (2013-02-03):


J3 − Arduino I2C Pins
Older Arduinos use A4/A5
Newer Arduinos use SDA/SCL

3 | 4 | SCL

Place C2 and C3 near LTC2499 VCC pin.

Local regulator to provide quiet 5V.
Can only be used when VIN is present.


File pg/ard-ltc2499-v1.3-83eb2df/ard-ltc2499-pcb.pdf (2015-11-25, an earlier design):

# ard-ltc2499.pcb

# 1. Table of Contents (This Page) Created on Wed Nov 25 10:30:26 2015

# 2. component 3. solder 4. outline 5. plated-drill 6. componentmask 7. soldermask 8. topsilk 9. bottomsilk 10. toppaste 11. topassembly 12. bottomassembly 13. fab

top, scale = 1:1.000


bottom (mirrored), scale = 1:1.000

outline, scale = 1:1.000


plated-drill, scale = 1:1.000

topmask, scale = 1:1.000


bottommask (mirrored), scale = 1:1.000

topsilk, scale = 1:1.000

bottomsilk (mirrored), scale = 1:1.000

toppaste, scale = 1:1.000

topassembly, scale = 1:1.000


bottomassembly (mirrored), scale = 1:1.000

fab, scale = 1:1.000

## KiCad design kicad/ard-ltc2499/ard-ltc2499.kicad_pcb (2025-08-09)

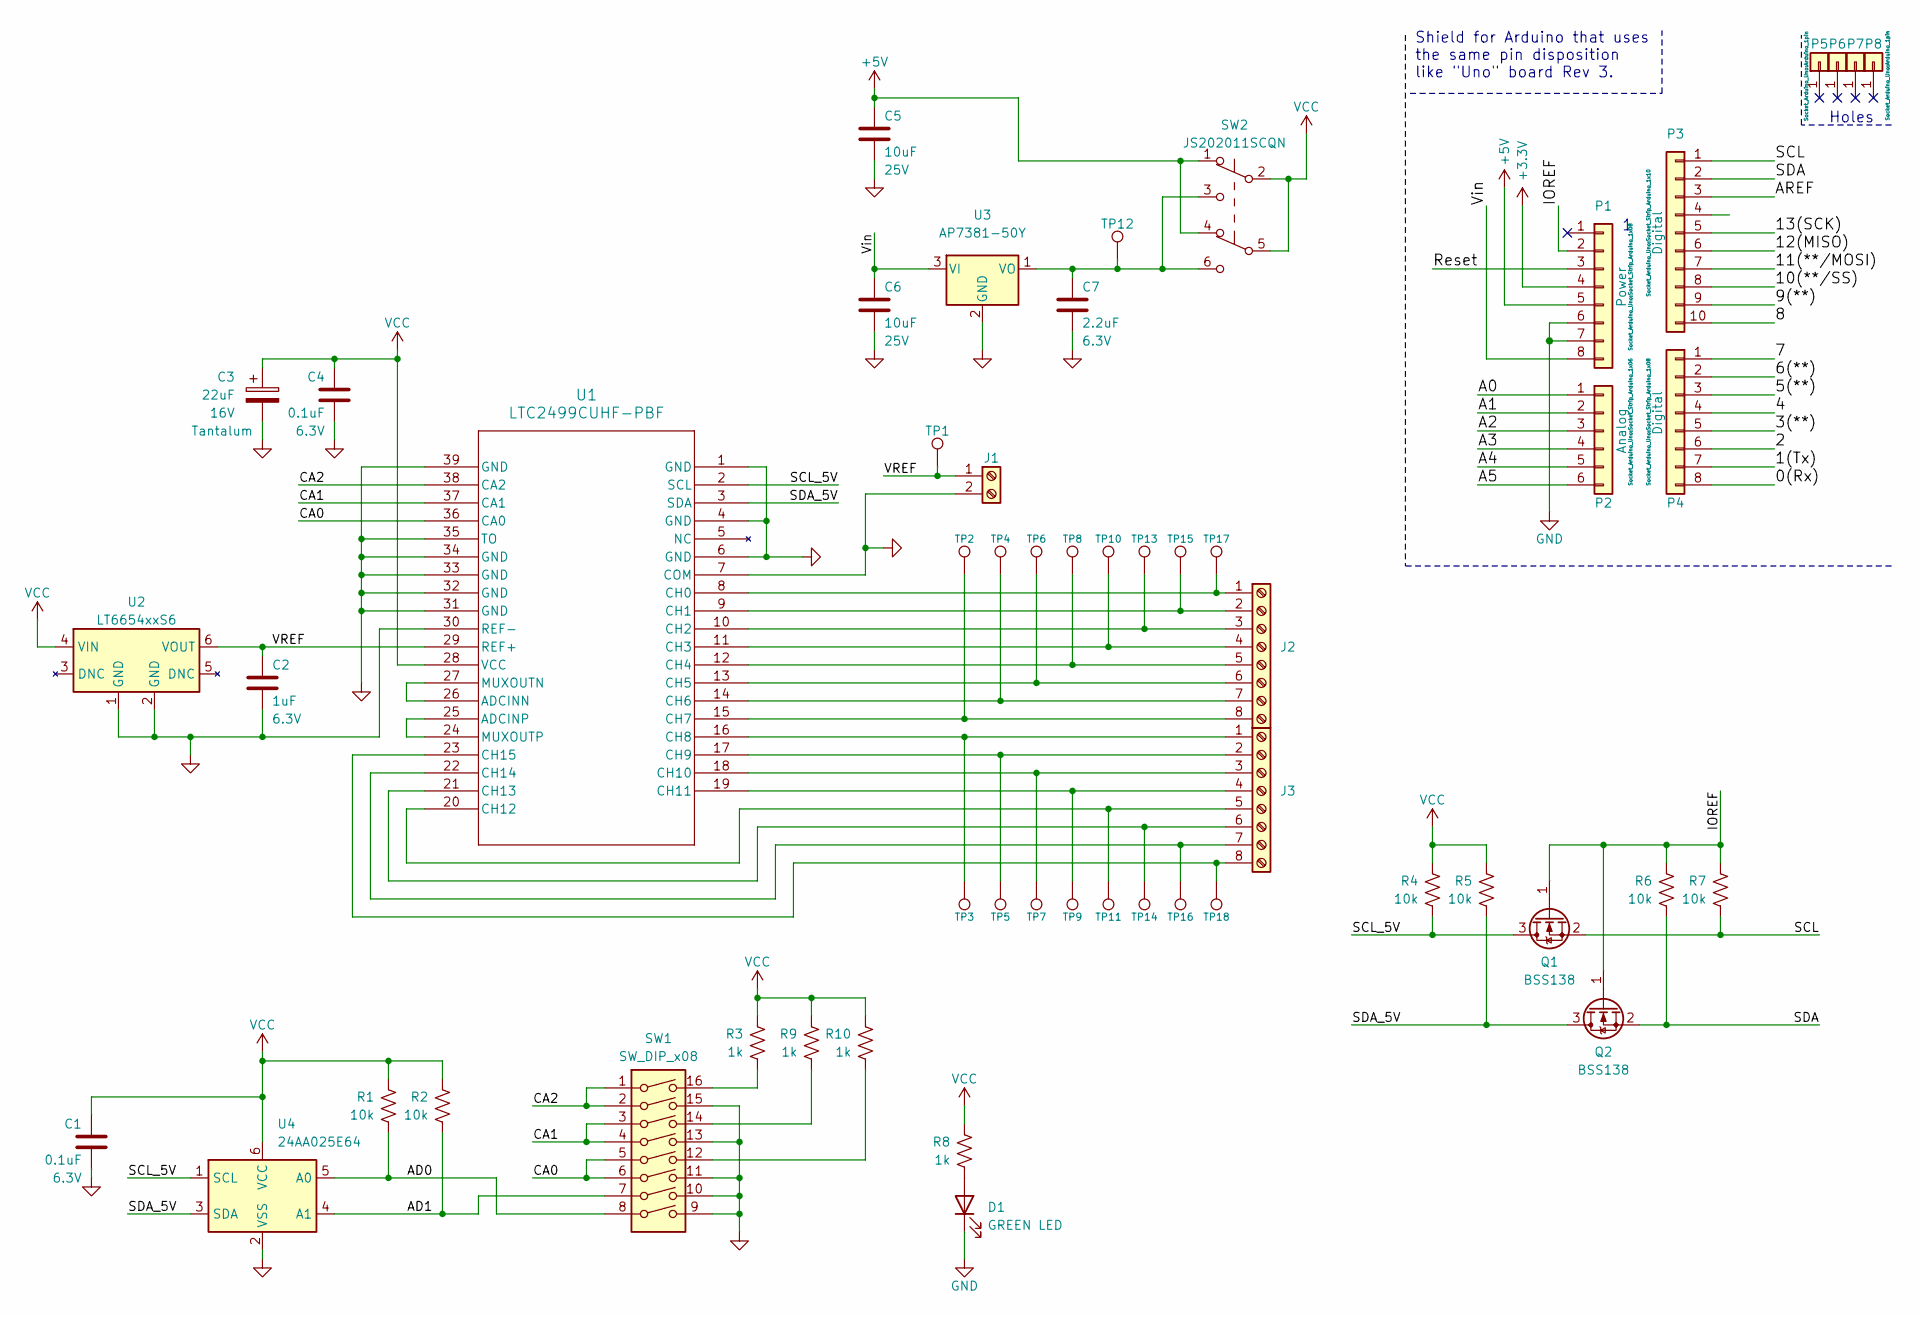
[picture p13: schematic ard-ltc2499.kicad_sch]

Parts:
C1, C4: 0.1uF; C_0805_2012Metric; Voltage 6.3V
C2: 1uF; C_0805_2012Metric; Voltage 6.3V
C3: 22uF; CP_EIA-3216-18_Kemet-A; Voltage 16V
C5, C6: 10uF; C_0805_2012Metric; Voltage 25V
C7: 2.2uF; C_0805_2012Metric; Voltage 6.3V
D1: GREEN LED; LED_0805_2012Metric
J1: Screw_Terminal_01x02; TerminalBlock_RND_205-00012_1x02_P5.00mm_Horizontal
J2, J3: Screw_Terminal_01x08; TerminalBlock_TE_282834-8_1x08_P2.54mm_Horizontal
P1: Power; Socket_Strip_Arduino_1x08
P2: Analog; Socket_Strip_Arduino_1x06
P3: Digital; Socket_Strip_Arduino_1x10
P4: Digital; Socket_Strip_Arduino_1x08
P5, P6, P7, P8: CONN_01X01; Arduino_1pin
Q1, Q2: BSS138; SOT-23
R1, R2, R4, R5, R6, R7: 10k; R_0805_2012Metric
R3, R8, R9, R10: 1k; R_0805_2012Metric
SW1: SW_DIP_x08; SW_DIP_SPSTx08_Slide_6.7x21.88mm_W8.61mm_P2.54mm_LowProfile
SW2: JS202011SCQN; SW_JS202011SCQN
TP1, TP2, TP3, TP4, TP5, TP6, TP7, TP8, TP9, TP10, TP11, TP12, TP13, TP14, TP15, TP16, TP17, TP18: TestPoint; TestPoint_Pad_D1.5mm
U1: LTC2499CUHF-PBF; QFN-38_UHF_LIT
U2: LT6654xxS6; TSOT-23-6
U3: AP7381-50Y; SOT-89-3
U4: 24AA025E64; TSOT-23-6

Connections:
+3V3: P1.4
+5V: C5.1, P1.5, SW2.1 (A), SW2.4 (A)
/0(Rx): P4.8
/1(Tx): P4.7
/2: P4.6
/3(**): P4.5
/4: P4.4
/5(**): P4.3
/6(**): P4.2
/7: P4.1
/8: P3.10
/9(**): P3.9
/10(**/SS): P3.8
/11(**/MOSI): P3.7
/12(MISO): P3.6
/13(SCK): P3.5
/A0: P2.1
/A1: P2.2
/A2: P2.3
/A3: P2.4
/A4: P2.5
/A5: P2.6
/AD0: R1.1, SW1.8, U4.5 (A0)
/AD1: R2.1, SW1.7, U4.4 (A1)
/AREF: P3.3
/CA0: SW1.5, SW1.6, U1.36 (CA0)
/CA1: SW1.3, SW1.4, U1.37 (CA1)
/CA2: SW1.1, SW1.2, U1.38 (CA2)
/IOREF: P1.2, Q1.1 (G), Q2.1 (G), R6.2, R7.2
/Reset: P1.3
/SCL: P3.1, Q1.2 (S), R7.1
/SCL_5V: Q1.3 (D), R4.1, U1.2 (SCL), U4.1 (SCL)
/SDA: P3.2, Q2.2 (S), R6.1
/SDA_5V: Q2.3 (D), R5.1, U1.3 (SDA), U4.3 (SDA)
/VREF: C2.1, J1.1, TP1.1, U1.29 (REF+), U2.6 (VOUT)
/Vin: C6.1, P1.8, U3.3 (VI)
GND: C1.2, C2.2, C3.2, C4.2, C5.2, C6.2, C7.2, D1.1 (K), J1.2, P1.6, P1.7, SW1.9, SW1.10, SW1.11, SW1.13, SW1.15, U1.1 (GND), U1.4 (GND), U1.6 (GND), U1.7 (COM), U1.30 (REF-), U1.31 (GND), U1.32 (GND), U1.33 (GND), U1.34 (GND), U1.35 (TO), U1.39 (GND), U2.1 (GND), U2.2 (GND), U3.2 (GND), U4.2 (VSS)
unnamed: C7.1, SW2.3 (C), SW2.6 (C), TP12.1, U3.1 (VO)
unnamed: D1.2 (A), R8.1
unnamed: J2.1, TP17.1, U1.8 (CH0)
unnamed: J2.2, TP15.1, U1.9 (CH1)
unnamed: J2.3, TP13.1, U1.10 (CH2)
unnamed: J2.4, TP10.1, U1.11 (CH3)
unnamed: J2.5, TP8.1, U1.12 (CH4)
unnamed: J2.6, TP6.1, U1.13 (CH5)
unnamed: J2.7, TP4.1, U1.14 (CH6)
unnamed: J2.8, TP2.1, U1.15 (CH7)
unnamed: J3.1, TP3.1, U1.16 (CH8)
unnamed: J3.2, TP5.1, U1.17 (CH9)
unnamed: J3.3, TP7.1, U1.18 (CH10)
unnamed: J3.4, TP9.1, U1.19 (CH11)
unnamed: J3.5, TP11.1, U1.20 (CH12)
unnamed: J3.6, TP14.1, U1.21 (CH13)
unnamed: J3.7, TP16.1, U1.22 (CH14)
unnamed: J3.8, TP18.1, U1.23 (CH15)
unnamed: R3.1, SW1.16
unnamed: R9.1, SW1.14
unnamed: R10.1, SW1.12
unnamed: U1.24 (MUXOUTP), U1.25 (ADCINP)
unnamed: U1.26 (ADCINN), U1.27 (MUXOUTN)
VCC: C1.1, C3.1, C4.1, R1.2, R2.2, R3.2, R4.2, R5.2, R8.2, R9.2, R10.2, SW2.2 (B), SW2.5 (B), U1.28 (VCC), U2.4 (VIN), U4.6 (VCC)

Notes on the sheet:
Holes
Shield for Arduino that uses the same pin disposition like "Uno" board Rev 3.

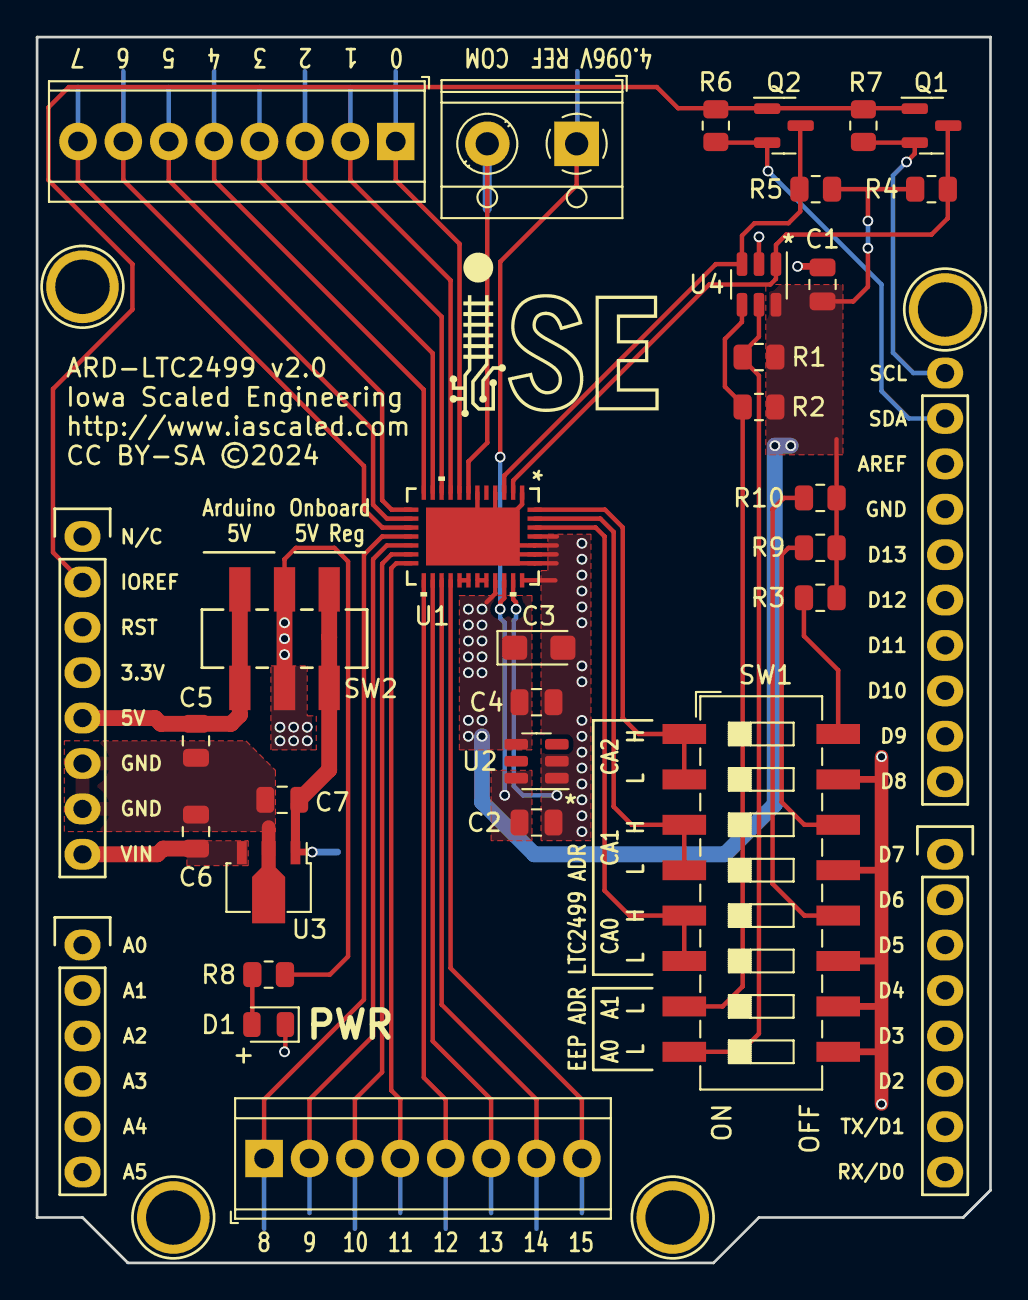
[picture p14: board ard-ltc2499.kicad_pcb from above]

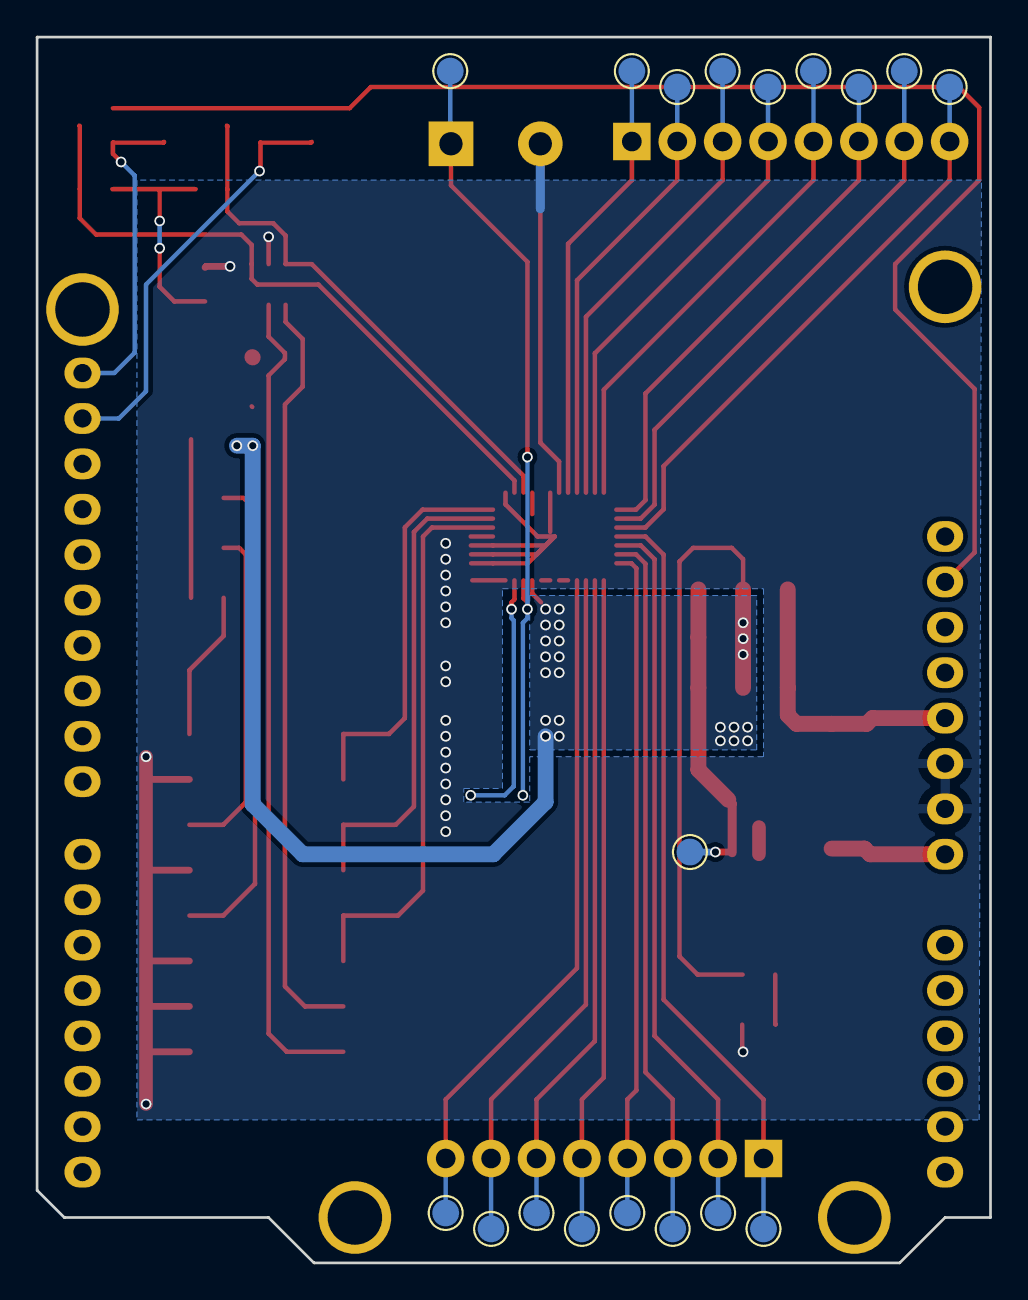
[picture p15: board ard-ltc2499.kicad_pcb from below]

Board: 2 copper layers, 53.3 x 68.6 mm, 55 parts (18 on the bottom side), 38 nets.

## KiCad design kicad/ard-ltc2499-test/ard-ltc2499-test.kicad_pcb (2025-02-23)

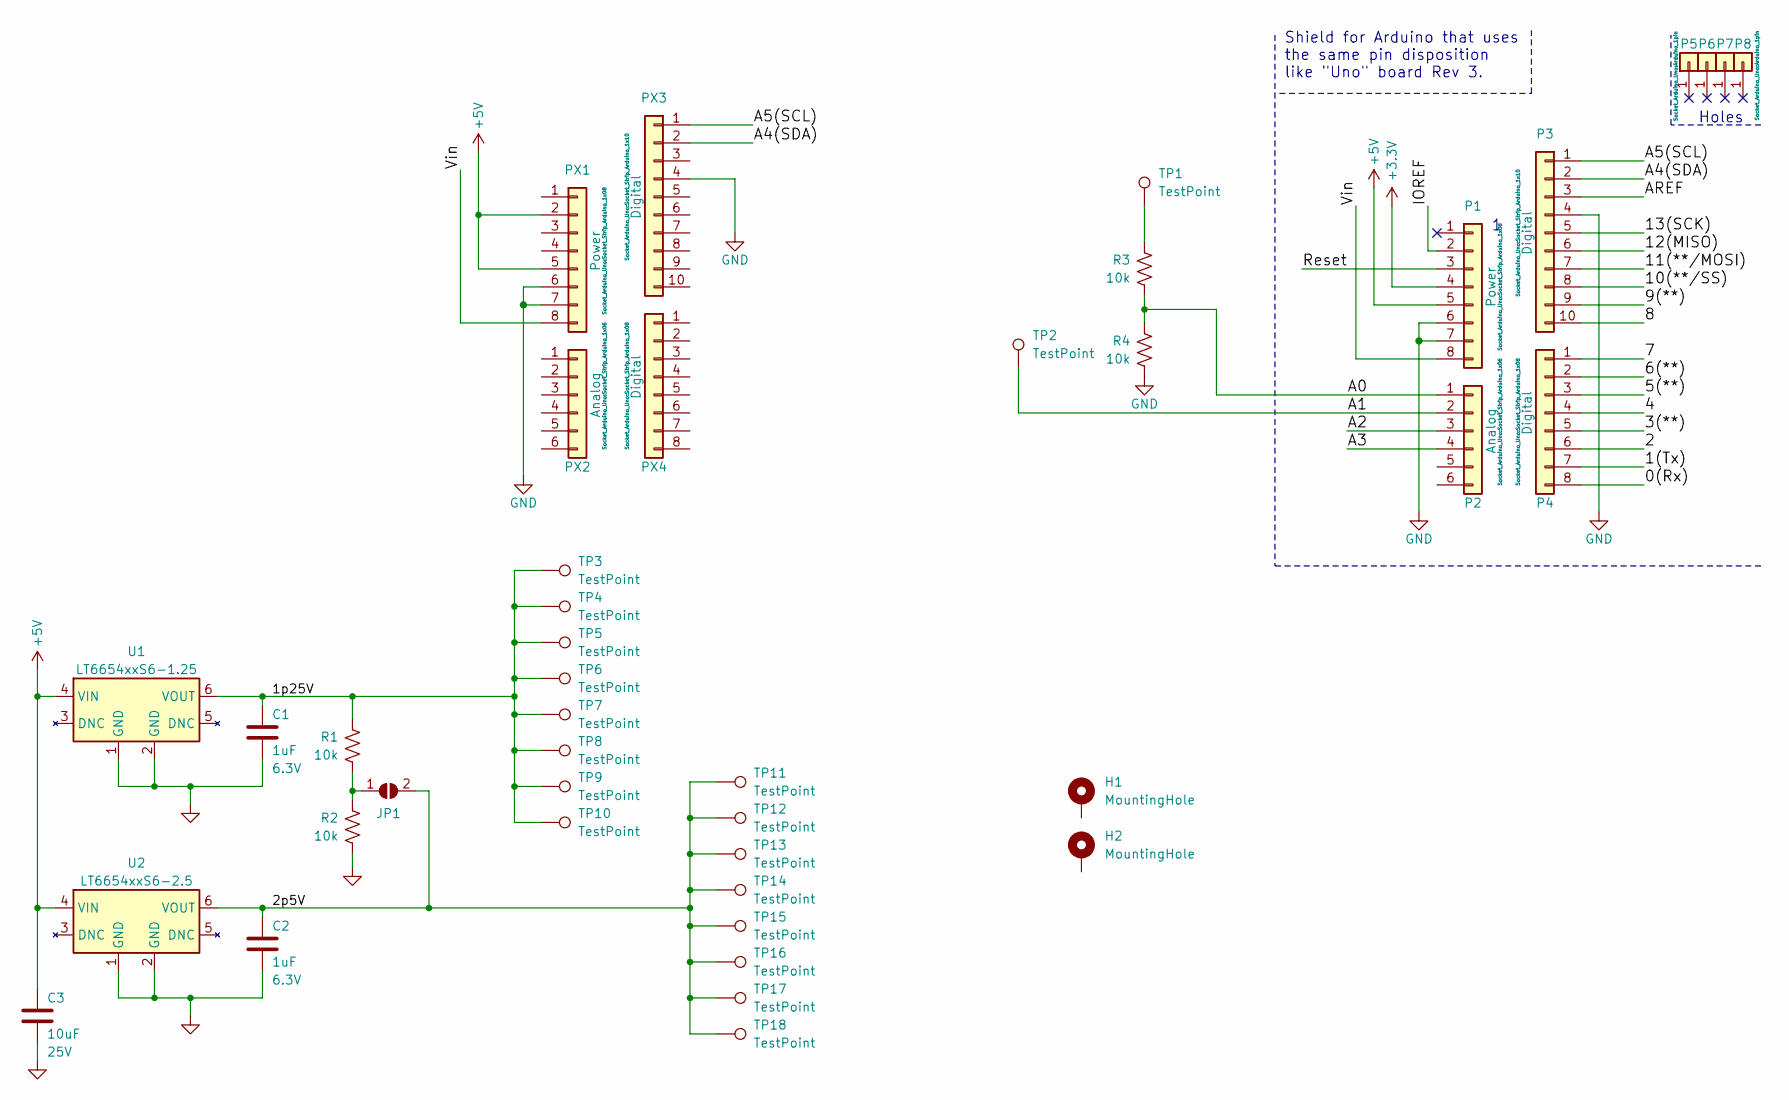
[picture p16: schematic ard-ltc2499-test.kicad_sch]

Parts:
C1, C2: 1uF; C_0805_2012Metric; Voltage 6.3V
C3: 10uF; C_0805_2012Metric; Voltage 25V
H1, H2: MountingHole; MountingHole_3.2mm_M3_Pad
JP1: SolderJumper_2_Open; SolderJumper-2_P1.3mm_Open_RoundedPad1.0x1.5mm
P1: Power; Socket_Strip_Arduino_1x08
P2: Analog; Socket_Strip_Arduino_1x06
P3: Digital; Socket_Strip_Arduino_1x10
P4: Digital; Socket_Strip_Arduino_1x08
P5, P6, P7, P8: CONN_01X01; Arduino_1pin
PX1: Power; Socket_Strip_Arduino_1x08
PX2: Analog; Socket_Strip_Arduino_1x06
PX3: Digital; Socket_Strip_Arduino_1x10
PX4: Digital; Socket_Strip_Arduino_1x08
R1, R2, R3, R4: 10k; R_0805_2012Metric
TP1, TP2, TP3, TP4, TP5, TP6, TP7, TP8, TP9, TP10, TP11, TP12, TP13, TP14, TP15, TP16, TP17, TP18: TestPoint; PinHeader_1x01_P2.54mm_Vertical
U1: LT6654xxS6-1.25; TSOT-23-6
U2: LT6654xxS6-2.5; TSOT-23-6

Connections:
+3V3: P1.4
+5V: C3.1, P1.5, PX1.2, PX1.5, U1.4 (VIN), U2.4 (VIN)
/0(Rx): P4.8
/1(Tx): P4.7
/1p25V: C1.1, R1.2, TP3.1, TP4.1, TP5.1, TP6.1, TP7.1, TP8.1, TP9.1, TP10.1, U1.6 (VOUT)
/2: P4.6
/2p5V: C2.1, JP1.2 (B), TP11.1, TP12.1, TP13.1, TP14.1, TP15.1, TP16.1, TP17.1, TP18.1, U2.6 (VOUT)
/3(**): P4.5
/4: P4.4
/5(**): P4.3
/6(**): P4.2
/7: P4.1
/8: P3.10
/9(**): P3.9
/10(**/SS): P3.8
/11(**/MOSI): P3.7
/12(MISO): P3.6
/13(SCK): P3.5
/A0: P2.1, R3.1, R4.2
/A1: P2.2, TP2.1
/A2: P2.3
/A3: P2.4
/A4(SDA): P3.2, PX3.2
/A5(SCL): P3.1, PX3.1
/AREF: P3.3
/IOREF: P1.2
/Reset: P1.3
/Vin: P1.8, PX1.8
GND: C1.2, C2.2, C3.2, P1.6, P1.7, P3.4, PX1.6, PX1.7, PX3.4, R2.1, R4.1, U1.1 (GND), U1.2 (GND), U2.1 (GND), U2.2 (GND)
unnamed: JP1.1 (A), R1.1, R2.2
unnamed: R3.2, TP1.1

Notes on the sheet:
Holes
Shield for Arduino that uses the same pin disposition like "Uno" board Rev 3.

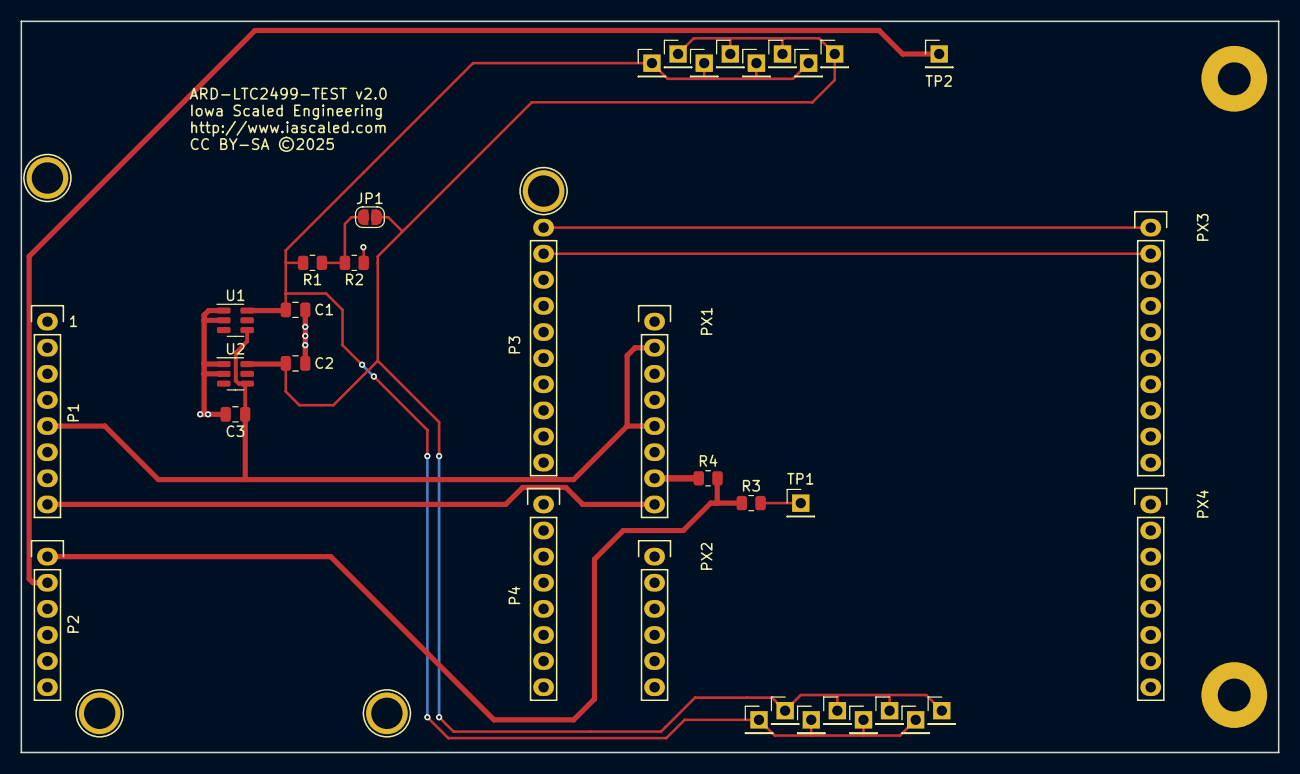
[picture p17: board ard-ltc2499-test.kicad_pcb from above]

Board: 2 copper layers, 122.3 x 71.1 mm, 42 parts (0 on the bottom side), 11 nets.

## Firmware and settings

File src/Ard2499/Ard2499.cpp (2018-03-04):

/*************************************************************************
Title:    ARD-LTC2499 Driver Library
Authors:  Nathan D. Holmes <maverick@drgw.net>
File:     $Id: $
License:  GNU General Public License v3

LICENSE:
    Copyright (C) 2013 Nathan D. Holmes & Michael D. Petersen

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
*************************************************************************/

#include <stdlib.h>
#include <string.h>

#include "Ard2499.h"

byte Ard2499::ltc2499ChangeChannel(byte channel)
{
	return(ltc2499ChangeChannel(channel, true));
}

byte Ard2499::ltc2499ChangeChannel(byte channel, bool addStop)
{
	uint8_t config1=0, config2=0, blockingCountdown;	
	
	if (LTC2499_CHAN_TEMPERATURE == channel)
	{
		// The temperature channel is fake - it really has to change the config byte in the message
		current2499Channel = LTC2499_CHAN_TEMPERATURE;
		config1 = 0x80 | _BV(LTC2499_CONFIG1_ENABLE);
		config2 = _BV(LTC2499_CONFIG2_ENABLE2) | _BV(LTC2499_CONFIG2_IM) | (LTC2499_CONFIG2_CONFBITS & current2499Config);
	}
	else
	{
		current2499Channel = LTC2499_CONFIG1_CHANBITS & channel;
		config1 = 0x80 | _BV(LTC2499_CONFIG1_ENABLE) | (0x1F & current2499Channel);
		config2 = _BV(LTC2499_CONFIG2_ENABLE2) | (LTC2499_CONFIG2_CONFBITS & current2499Config);
	}

	// If there's no ltc2499 address, error out
	if(0 == i2cAddr_ltc2499)
		return(ARD2499_LTC2499_ERR);

	// Block in 5ms increments for up to 200ms.  Given the conversion rate 
	// should be greater than 7.5sps, 200ms is more than we should ever have to
	// wait.

	blockingCountdown = 40;
	while(blockingCountdown--)
	{
		this->WireInterface->beginTransmission(i2cAddr_ltc2499);
		this->WireInterface->write(config1);
		this->WireInterface->write(config2);
		if (0 != this->WireInterface->endTransmission(addStop))
		{
			if (0 == blockingCountdown)
				return(ARD2499_LTC2499_ERR);
			delay(5);
		}	
		else
			break;
	}

	return(ARD2499_SUCCESS);
}

byte Ard2499::ltc2499ChangeConfiguration(byte config)
{
	current2499Config = LTC2499_CONFIG2_CONFBITS & config;
	return(ltc2499ChangeChannel(current2499Channel));
}

long Ard2499::ltc2499Read()
{
	unsigned long rawValue = ltc2499ReadRaw();
	
	if (LTC2499_RAW_READ_ERROR == rawValue)
		return(LTC2499_READ_ERROR);

	uint8_t upperByte = 0xFF & (rawValue>>24);
	switch(upperByte)
	{
		case 0xC0:
			return(LTC2499_OVERRANGE_POSITIVE);
		case 0x3F:
			return(LTC2499_OVERRANGE_NEGATIVE);
	}
	rawValue = (rawValue & 0x7FFFFFFF)>>6; // Get rid of the sub-LSBs

	if (0x01000000 & rawValue)
		rawValue |= 0xFF000000;
	return((long)rawValue);

}

float Ard2499::ltc2499ReadVoltage()
{
	long value = ltc2499Read();
	
	if (LTC2499_OVERRANGE_POSITIVE == value)
		return(INFINITY);
	if (LTC2499_OVERRANGE_NEGATIVE == value)
		return(-1*INFINITY);

	return((value / 16777216.0) * (referenceMillivolts / 2000.0));
}

float Ard2499::ltc2499ReadVoltageAndChangeChannel(byte nextChannel)
{
	long value = ltc2499ReadAndChangeChannel(nextChannel);
	
	if (LTC2499_OVERRANGE_POSITIVE == value)
		return(INFINITY);
	if (LTC2499_OVERRANGE_NEGATIVE == value)
		return(-1*INFINITY);

	return((value / 16777216.0) * (referenceMillivolts / 2000.0));
}

long Ard2499::ltc2499ReadAndChangeChannel(byte nextChannel)
{
	if (ARD2499_SUCCESS != ltc2499ChangeChannel(nextChannel, false))
	{
		// Run another transmission through just to send out a stop bit
		this->WireInterface->beginTransmission(i2cAddr_ltc2499);
		this->WireInterface->endTransmission((uint8_t)true);
		return(LTC2499_READ_ERROR);
	}
	// Otherwise, we've succeeded and are sitting on a restart condition
	return(ltc2499Read());
}

unsigned long Ard2499::ltc2499ReadRaw()
{
	unsigned long retval=0;
	uint8_t blockingCountdown=40;

	if (0 == i2cAddr_ltc2499)
		return(0);

	// Block in 5ms increments for up to 200ms.  Given the conversion rate 
	// should be greater than 7.5sps, 200ms is more than we should ever have to
	// wait.
	while(blockingCountdown--)
	{
		this->WireInterface->requestFrom((uint8_t)i2cAddr_ltc2499, (uint8_t)4, (uint8_t)true);
		// Error occurred, we don't have as many bytes as expected
		if (this->WireInterface->available() < 4)
		{
			if (0 == blockingCountdown)
				return(LTC2499_RAW_READ_ERROR);
			delay(5);
		}	
		else
			break;
	}

	retval |= this->WireInterface->read();
	retval <<= 8;
	retval |= this->WireInterface->read();
	retval <<= 8;
	retval |= this->WireInterface->read();
	retval <<= 8;
	retval |= this->WireInterface->read();

	return(retval);
}

unsigned long Ard2499::ltc2499ReadRawAndChangeChannel(byte nextChannel)
{
	if (ARD2499_SUCCESS != ltc2499ChangeChannel(nextChannel, false))
	{
		// Run another transmission through just to send out a stop bit
		this->WireInterface->beginTransmission(i2cAddr_ltc2499);
		this->WireInterface->endTransmission((uint8_t)true);
		return(LTC2499_RAW_READ_ERROR);
	}
	// Otherwise, we've succeeded and are sitting on a restart condition
	return(ltc2499ReadRaw());
}

float Ard2499::ltc2499ReadTemperature(byte temperatureUnits)
{
	unsigned int tempDK = ltc2499ReadTemperatureDeciK();
	float tempK = (float)tempDK/10.0;
	switch(temperatureUnits)
	{
		case ARD2499_TEMP_K:
			return(tempK);
		case ARD2499_TEMP_C:
			return(tempK - 273.15);
		case ARD2499_TEMP_F:
			return(((tempK - 273.15) * 9.0)  / 5.0 + 32.0);
	}
	return(0);
}

unsigned int Ard2499::ltc2499ReadTemperatureDeciK()
{
	unsigned long readVal = 0;
	unsigned long tempDK = 0;
	
	// If we're currently not set for the temperature channel, switch us over
	// If we are currently set for the temp channel, then that write will have
	// triggered a conversion, and ltc2499ReadRaw will block until it's done
	if(LTC2499_CHAN_TEMPERATURE != current2499Channel)
		ltc2499ChangeChannel(LTC2499_CHAN_TEMPERATURE, true);
	
	readVal = ltc2499ReadRaw();
	
	if (LTC2499_RAW_READ_ERROR == readVal)
		return(0);

	// Throw away the sub-LSBs
	readVal >>= 6;

	tempDK = (0x00FFFFFF & readVal);
	// Divide by 2 for FS = 1/2 VREF
	// Divide by 1570 (eqn from 2499 datasheet)
	// Divide by 100 to convert millivolts to decivolts
	tempDK = (tempDK * (unsigned long)referenceMillivolts) / 314000;

	// tempDK is now the temperature in deci-kelvin
	return(tempDK);
}

Ard2499::Ard2499()
{
	init_status = ARD2499_LTC2499_ERR | ARD2499_EEPROM_ERR;
	i2cAddr_ltc2499 = 0;
	i2cAddr_eeprom = 0;
	current2499Config = 0;
	current2499Channel = 0;

#ifdef ARDUINO_SAM_DUE
	WireInterface = &Wire1;
#else 
	WireInterface = &Wire;
#endif

	strcpy(eui48, "Unknown");
}

Ard2499::Ard2499(TwoWire& wire)
{
	Ard2499();
	this->WireInterface = &wire;
}


const char* Ard2499::eui48Get()
{
	return(eui48);
}
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

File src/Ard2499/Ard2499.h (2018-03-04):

/*************************************************************************
Title:    ARD-LTC2499 Driver Library
Authors:  Nathan D. Holmes <maverick@drgw.net>
File:     $Id: $
License:  GNU General Public License v3

LICENSE:
    Copyright (C) 2013 Nathan D. Holmes & Michael D. Petersen

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
*************************************************************************/
#ifndef ARD2499_H
#define ARD2499_H

#include <stdlib.h>
#include <string.h>
#include "Arduino.h"
#include "Wire.h"

#ifndef _BV
#define _BV(a) (1<<(a))
#define _UNDEFINE_BV
#endif

#define FAKE_CONFIG1_TEMPERATURE   6
#define LTC2499_CONFIG1_ENABLE     5
#define LTC2499_CONFIG1_SINGLE_END 4
#define LTC2499_CONFIG1_ODD        3
#define LTC2499_CONFIG1_A2         2
#define LTC2499_CONFIG1_A1         1
#define LTC2499_CONFIG1_A0         0

#define LTC2499_CHAN_DIFF_0P_1N    (0)
#define LTC2499_CHAN_DIFF_2P_3N    (_BV(LTC2499_CONFIG1_A0))
#define LTC2499_CHAN_DIFF_4P_5N    (_BV(LTC2499_CONFIG1_A1))
#define LTC2499_CHAN_DIFF_6P_7N    (_BV(LTC2499_CONFIG1_A1) | _BV(LTC2499_CONFIG1_A0))
#define LTC2499_CHAN_DIFF_8P_9N    (_BV(LTC2499_CONFIG1_A2))
#define LTC2499_CHAN_DIFF_10P_11N  (_BV(LTC2499_CONFIG1_A2) | _BV(LTC2499_CONFIG1_A0))
#define LTC2499_CHAN_DIFF_12P_13N  (_BV(LTC2499_CONFIG1_A2) | _BV(LTC2499_CONFIG1_A1))
#define LTC2499_CHAN_DIFF_14P_15N  (_BV(LTC2499_CONFIG1_A2) | _BV(LTC2499_CONFIG1_A1) | _BV(LTC2499_CONFIG1_A0))

#define LTC2499_CHAN_DIFF_1P_0N    (_BV(LTC2499_CONFIG1_ODD))
#define LTC2499_CHAN_DIFF_3P_2N    (_BV(LTC2499_CONFIG1_ODD) | _BV(LTC2499_CONFIG1_A0))
#define LTC2499_CHAN_DIFF_5P_4N    (_BV(LTC2499_CONFIG1_ODD) | _BV(LTC2499_CONFIG1_A1))
#define LTC2499_CHAN_DIFF_7P_6N    (_BV(LTC2499_CONFIG1_ODD) | _BV(LTC2499_CONFIG1_A1) | _BV(LTC2499_CONFIG1_A0))
#define LTC2499_CHAN_DIFF_9P_8N    (_BV(LTC2499_CONFIG1_ODD) | _BV(LTC2499_CONFIG1_A2))
#define LTC2499_CHAN_DIFF_11P_10N  (_BV(LTC2499_CONFIG1_ODD) | _BV(LTC2499_CONFIG1_A2) | _BV(LTC2499_CONFIG1_A0))
#define LTC2499_CHAN_DIFF_13P_12N  (_BV(LTC2499_CONFIG1_ODD) | _BV(LTC2499_CONFIG1_A2) | _BV(LTC2499_CONFIG1_A1))
#define LTC2499_CHAN_DIFF_15P_14N  (_BV(LTC2499_CONFIG1_ODD) | _BV(LTC2499_CONFIG1_A2) | _BV(LTC2499_CONFIG1_A1) | _BV(LTC2499_CONFIG1_A0))

#define LTC2499_CHAN_SINGLE_0P     (_BV(LTC2499_CONFIG1_SINGLE_END))
#define LTC2499_CHAN_SINGLE_1P     (_BV(LTC2499_CONFIG1_SINGLE_END) | _BV(LTC2499_CONFIG1_ODD))
#define LTC2499_CHAN_SINGLE_2P     (_BV(LTC2499_CONFIG1_SINGLE_END) | _BV(LTC2499_CONFIG1_A0))
#define LTC2499_CHAN_SINGLE_3P     (_BV(LTC2499_CONFIG1_SINGLE_END) | _BV(LTC2499_CONFIG1_ODD) | _BV(LTC2499_CONFIG1_A0))
#define LTC2499_CHAN_SINGLE_4P     (_BV(LTC2499_CONFIG1_SINGLE_END) | _BV(LTC2499_CONFIG1_A1))
#define LTC2499_CHAN_SINGLE_5P     (_BV(LTC2499_CONFIG1_SINGLE_END) | _BV(LTC2499_CONFIG1_ODD) | _BV(LTC2499_CONFIG1_A1))
#define LTC2499_CHAN_SINGLE_6P     (_BV(LTC2499_CONFIG1_SINGLE_END) | _BV(LTC2499_CONFIG1_A1) | _BV(LTC2499_CONFIG1_A0))
#define LTC2499_CHAN_SINGLE_7P     (_BV(LTC2499_CONFIG1_SINGLE_END) | _BV(LTC2499_CONFIG1_ODD) | _BV(LTC2499_CONFIG1_A1) | _BV(LTC2499_CONFIG1_A0))
#define LTC2499_CHAN_SINGLE_8P     (_BV(LTC2499_CONFIG1_SINGLE_END) | _BV(LTC2499_CONFIG1_A2))
#define LTC2499_CHAN_SINGLE_9P     (_BV(LTC2499_CONFIG1_SINGLE_END) | _BV(LTC2499_CONFIG1_ODD) | _BV(LTC2499_CONFIG1_A2))
#define LTC2499_CHAN_SINGLE_10P    (_BV(LTC2499_CONFIG1_SINGLE_END) | _BV(LTC2499_CONFIG1_A2) | _BV(LTC2499_CONFIG1_A0))
#define LTC2499_CHAN_SINGLE_11P    (_BV(LTC2499_CONFIG1_SINGLE_END) | _BV(LTC2499_CONFIG1_ODD) | _BV(LTC2499_CONFIG1_A2) | _BV(LTC2499_CONFIG1_A0))
#define LTC2499_CHAN_SINGLE_12P    (_BV(LTC2499_CONFIG1_SINGLE_END) | _BV(LTC2499_CONFIG1_A2) | _BV(LTC2499_CONFIG1_A1))
#define LTC2499_CHAN_SINGLE_13P    (_BV(LTC2499_CONFIG1_SINGLE_END) | _BV(LTC2499_CONFIG1_ODD) | _BV(LTC2499_CONFIG1_A2) | _BV(LTC2499_CONFIG1_A1))
#define LTC2499_CHAN_SINGLE_14P    (_BV(LTC2499_CONFIG1_SINGLE_END) | _BV(LTC2499_CONFIG1_A2) | _BV(LTC2499_CONFIG1_A1) | _BV(LTC2499_CONFIG1_A0))
#define LTC2499_CHAN_SINGLE_15P    (_BV(LTC2499_CONFIG1_SINGLE_END) | _BV(LTC2499_CONFIG1_ODD) | _BV(LTC2499_CONFIG1_A2) | _BV(LTC2499_CONFIG1_A1) | _BV(LTC2499_CONFIG1_A0))

// The temperature channel is actually fake - we manipulate things internally
#define LTC2499_CHAN_TEMPERATURE   (_BV(FAKE_CONFIG1_TEMPERATURE))

#define LTC2499_CONFIG2_ENABLE2     7
#define LTC2499_CONFIG2_IM          6
#define LTC2499_CONFIG2_FA          5
#define LTC2499_CONFIG2_FB          4
#define LTC2499_CONFIG2_SPD         3

#define LTC2499_CONFIG2_50HZ_REJ    (_BV(LTC2499_CONFIG2_FB))
#define LTC2499_CONFIG2_60HZ_REJ    (_BV(LTC2499_CONFIG2_FA))
#define LTC2499_CONFIG2_60_50HZ_REJ (0)  
#define LTC2499_CONFIG2_SPEED_2X    (_BV(LTC2499_CONFIG2_SPD))

#define LTC2499_CONFIG1_CHANBITS (_BV(LTC2499_CONFIG1_SINGLE_END) | _BV(LTC2499_CONFIG1_ODD) | _BV(LTC2499_CONFIG1_A2) | _BV(LTC2499_CONFIG1_A1) | _BV(LTC2499_CONFIG1_A0))
#define LTC2499_CONFIG2_CONFBITS (_BV(LTC2499_CONFIG2_FA) | _BV(LTC2499_CONFIG2_FB) | _BV(LTC2499_CONFIG2_SPD))


#define ARD2499_SUCCESS      0
#define ARD2499_LTC2499_ERR  1
#define ARD2499_EEPROM_ERR   2

#define ARD2499_EEPROM_ADDR_EUI48  0xFA

#define ARD2499_EEP_ADDR_00 0x50
#define ARD2499_EEP_ADDR_0Z 0x51
#define ARD2499_EEP_ADDR_Z0 0x52
#define ARD2499_EEP_ADDR_ZZ 0x53

#define ARD2499_ADC_ADDR_000   0x14
#define ARD2499_ADC_ADDR_00Z   0x15
#define ARD2499_ADC_ADDR_001   0x16
#define ARD2499_ADC_ADDR_0Z0   0x17
#define ARD2499_ADC_ADDR_0ZZ   0x24
#define ARD2499_ADC_ADDR_0Z1   0x25
#define ARD2499_ADC_ADDR_010   0x26
#define ARD2499_ADC_ADDR_01Z   0x27
#define ARD2499_ADC_ADDR_011   0x28
#define ARD2499_ADC_ADDR_Z00   0x35
#define ARD2499_ADC_ADDR_Z01   0x37
#define ARD2499_ADC_ADDR_Z0Z   0x36
#define ARD2499_ADC_ADDR_ZZ0   0x44
#define ARD2499_ADC_ADDR_ZZZ   0x45
#define ARD2499_ADC_ADDR_ZZ1   0x46
#define ARD2499_ADC_ADDR_Z10   0x47
#define ARD2499_ADC_ADDR_Z1Z   0x54
#define ARD2499_ADC_ADDR_Z11   0x55
#define ARD2499_ADC_ADDR_100   0x56
#define ARD2499_ADC_ADDR_10Z   0x57
#define ARD2499_ADC_ADDR_101   0x64
#define ARD2499_ADC_ADDR_1Z0   0x65
#define ARD2499_ADC_ADDR_1ZZ   0x66
#define ARD2499_ADC_ADDR_1Z1   0x67
#define ARD2499_ADC_ADDR_110   0x74
#define ARD2499_ADC_ADDR_111   0x76
#define ARD2499_ADC_ADDR_11Z   0x75

#define ARD2499_TEMP_DEG_F     0x01

#define	ARD2499_TEMP_K        0x00
#define  ARD2499_TEMP_F        0x01
#define  ARD2499_TEMP_C        0x02

#define LTC2499_RAW_READ_ERROR     0xFFFFFFFF

#define LTC2499_READ_ERROR         0x01000001
#define LTC2499_OVERRANGE_POSITIVE 0x01000000
#define LTC2499_OVERRANGE_NEGATIVE 0x11000000
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

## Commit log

2013-01-29 Initial checkin. PCB not complete.
    [ard-ltc2499.sch]
2013-01-30 Finished PCB
    [ard-ltc2499.sch]
2013-01-31 Changed C2 to polarized.
    [ard-ltc2499.sch]
2013-02-02 Connected COM to GND. LVS/DRC Clean.
    [ard-ltc2499.sch]
2013-02-03 Add PG files.
    [ard-ltc2499.bottom.gbr, ard-ltc2499.bottommask.gbr, ard-ltc2499.fab.gbr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]
2013-03-18 Initial bit of the 2499 arduino library
2013-03-26 Rename directory to capitalize similar to other Arduino libraries
2013-03-27 Renamed the arduino example sketch Fixed a few bugs
    [Ard2499.cpp, Ard2499.h, ard2499_example.ino]
2013-03-27 Fixes to add gplv3 boilerplate
    [Ard2499.cpp, Ard2499.h]
2013-03-27 Forgot GPL stuff on arduino sketch
2013-10-12 Added start for HV capable version
    [ard-ltc2499hv.sch]
2013-11-25 Fixed LTC6654 to LT6654
    [ard-ltc2499.sch]
2014-03-19 Added alarm pin
2014-04-22 Added power LED. Added pin1 marks to U1, U2, U4
    [ard-ltc2499.sch]
2014-04-23 OSHPark order
    [ard-ltc2499.bottom.gbr, ard-ltc2499.bottommask.gbr, ard-ltc2499.bottompaste.gbr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]
2014-05-28 Changes to make it more widely arduino compatible
2014-10-31 Modified to use 4-pin SMT jumpers
    [ard-ltc2499.sch]
2014-10-31 Final layout with SMT
    [ard-ltc2499.sch]
2014-11-04 Updated 2499 footprint (smaller paste hole). LVS/DRC clean.
    [ard-ltc2499.sch]
2014-12-07 Fixed LTC2499_CONFIG2_CONFBITS - changed & to |
    [Ard2499.h]
2015-01-09 Update readme with more details about the board and ISE
2015-01-18 Modified channel test to check adjacent channel (looking for shorts)
    [ard2499_test.ino]
2015-04-21 Reversed the positive and negative overrange codes in the library. Somehow these have been backwards for years and I've never noticed.
    [Ard2499.cpp]
2015-05-03 Initial commit of volt meter sketch
2015-05-24 Added voltage measurement at end.
2015-07-26 Added note for expected voltage
2015-11-12 Increased annulus around arduino headers (sch/pcb). Changed LED to 0805 (sch only). Changed 2x3 header to SMT (sch only). Replaced R1-R4 with rpack (sch only).
    [ard-ltc2499.sch]
2015-11-12 PCB edits complete.
2015-11-25 New release for possible next production run
    [ard-ltc2499.bottom.gbr, ard-ltc2499.bottommask.gbr, ard-ltc2499.bottompaste.gbr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]
2016-01-21 Add ability to pass reference voltage in millivolts in the initializer
2016-01-23 Updated to support different Vref voltages
2016-01-28 Moved default reference voltage to function prototype so it's known when including the header file
2016-01-28 Fixed if/else logic in computeTemperatureTypeK - changed || to &&
    [ard_ltc2499_reflow.ino]
2016-12-23 Test fixture
    [test-ard-ltc2499.sch]
2016-12-26 Sent to fab 12/25/2016
    [test-ard-ltc2499.bottom.gbr, test-ard-ltc2499.bottommask.gbr, test-ard-ltc2499.bottompaste.gbr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]
2017-10-02 Support for Wire1 interface on the Due only Add another constructor such that a pointer to the correct wire interface can be passed in if the client wants to explicitly set it.
    [Ard2499.cpp, Ard2499.h]
2017-12-07 Added a change channel option to the read voltage function
2018-07-17 Arduino Nano design
    [nano-ltc2499.sch]
2018-07-28 Added text and 5V probe point
    [nano-ltc2499.sch]
2018-08-14 PG for nano version
    [nano-ltc2499.bottom.gbr, nano-ltc2499.bottommask.gbr, nano-ltc2499.bottompaste.gbr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]
2019-09-16 Mainline the level-shifted version of v1.3 from the level-shift branch
    [ard-ltc2499-ls.sch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]
2021-03-03 Add schematic links
2024-05-23 Initial schematic
    [ard-ltc2499.kicad_pcb, ard-ltc2499.kicad_sch]
2024-05-24 Fixed 6654 symbol
    [ard-ltc2499.kicad_sch]
2024-05-24 Added test points and individual address pull-ups
    [ard-ltc2499.kicad_sch]
2024-05-25 Updated PCB with schematic edits
    [ard-ltc2499.kicad_pcb]
2024-05-25 Initial placement
    [ard-ltc2499.kicad_pcb, ard-ltc2499.kicad_sch]
2024-05-25 Complete PCB
    [ard-ltc2499.kicad_pcb, ard-ltc2499.kicad_sch]
2024-05-25 Fixed typo
    [ard-ltc2499.kicad_pcb]
2024-05-25 Fixed terminal block 3D model height
    [ard-ltc2499.kicad_pcb]
2024-05-25 Adjusted text
    [ard-ltc2499.kicad_pcb]
2024-05-26 Minor tweaks
    [ard-ltc2499.kicad_pcb]
2024-05-28 Minor updates to text
    [ard-ltc2499.kicad_pcb]
2024-05-28 Minor adjustments to metal traces
    [ard-ltc2499.kicad_pcb]
2024-05-29 Clean up minor DRC warning
    [ard-ltc2499.kicad_pcb]
2024-05-29 pg v2.0
    [ard-ltc2499-NPTH.drl, ard-ltc2499.drl, ard-ltc2499.gbl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]
2025-02-01 Initial test board
    [ard-ltc2499-test.kicad_pcb, ard-ltc2499-test.kicad_sch]
2025-02-01 Added 5V divider and moved refernce divider to 1.25V
    [ard-ltc2499-test.kicad_pcb, ard-ltc2499-test.kicad_sch]
2025-02-23 Fixed courtyard errors
    [ard-ltc2499-test.kicad_pcb]
2025-02-23 Check in tester pg v1.0
    [ard-ltc2499-test-NPTH.drl, ard-ltc2499-test.drl, ard-ltc2499-test.gbl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]
2025-02-23 Fab files for the test jig
    [ard-ltc2499-test-NPTH.drl, ard-ltc2499-test.drl, ard-ltc2499-test.gbl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]
2025-02-23 Remove pg 1.0 of tester
    [ard-ltc2499-test-NPTH.drl, ard-ltc2499-test.drl, ard-ltc2499-test.gbl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]
2025-08-06 Add better models for pin headers to generate step file
    [ard-ltc2499.kicad_pcb]
2025-08-06 Remove old v1.x geda files to clean up repo
    [ard-ltc2499-ls.sch, ard-ltc2499.sch, ard-ltc2499hv.sch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]
2026-02-13 Switched to arduino-cli

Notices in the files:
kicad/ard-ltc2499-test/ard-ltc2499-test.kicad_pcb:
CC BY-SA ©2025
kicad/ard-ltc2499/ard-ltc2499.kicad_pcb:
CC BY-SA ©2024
